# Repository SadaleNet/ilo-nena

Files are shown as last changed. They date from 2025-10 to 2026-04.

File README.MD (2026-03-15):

**(English: Scrolldown for English | toki ike Inli li lon anpa pi toki pona)**

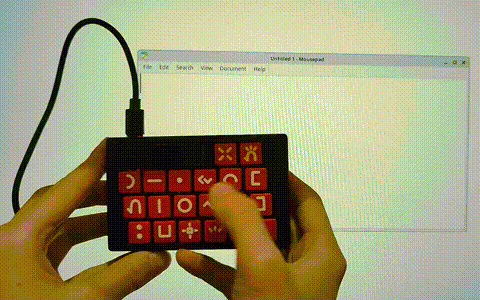
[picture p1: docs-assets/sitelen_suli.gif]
sitelen


* lipu: [https://ilonena.sadale.net/](https://ilonena.sadale.net/)
* sitelen tawa lon ilo Jutu "Youtube": [https://www.youtube.com/watch?v=uy7cPwKw794](https://www.youtube.com/watch?v=uy7cPwKw794)

# ilo nena - ilo pi nasin sitelen Wakalito

ilo nena ni li ken pali e sitelen pona tawa ilo sona kepeken nasin sitelen Wakalito. ilo nena la:

* nasin sitelen Wakalito li lon insa ona
* ken pana e sitelen pona tawa ilo sona kepeken [nasin UCSUR pi sitelen pona](https://www.kreativekorp.com/ucsur/charts/sitelen.html)
* ona li lili. ni li suli ona: 102mm x 64mm x 18mm
* jan li ken pilin e nena ali lon tenpo sama (ni li wile e lipu kiwen sona "PCB rev2")
	* lipu "PCB rev0" en lipu "PCB rev1" la jan li ken pilin e nena tu taso lon tenpo sama. sina ante ala e sona pi ilo nena la nena tu taso li pona. taso sina wile ante e sona ona la ken la sina wile e lipu "PCB rev2". ni la sina esun e lipu "PCB rev0" e lipu "PCB rev1" la o toki tawa mi. mi wile pana e ilo nena sin tawa sina kepeken mani ala.
* jan li ken pana e sona sin tawa ona kepeken nasin "USB"
* sona ali ona li lon. jan ali li ken lukin e ona li ante e ona li pali e ona
* jan li ken pali e ona mute kepeken mani lili kepeken tenpo lili

## nasin kepeken

sina wile kepeken ilo nena la o pali e ni lon ilo sona sina:

1. o kama jo e sitelen "[FairFax HD](https://www.kreativekorp.com/software/fonts/fairfaxhd/)"
2. ilo sona sina li kepeken nasin seme?
	* 🪟 nasin lupa "Windows": o kama jo e ilo [WinCompose](https://github.com/ell1010/wincompose). ilo nena li kepeken nena "R_ALT+U+NANPA".
	* 🐧 nasin soweli "Linux": o pali e ala. ilo nena li kepeken nena "CTRL+SHIFT+U+NANPA"
	* 🍎 nasin kili "Mac OS": o kama jo e nasin "Unicode Hex Input" lon ilo sona sina. ilo nena li kepeken nena "Option+NANPA"
	* nasin ante: ilo nena li ken pana e sitelen Lasin e sitelen UCSUR ala.
3. o kepeken linja "USB". kepeken linja ni la ilo sona sina en ilo nena li kama wan. kin la ilo nena li kama jo e wawa
4. o pilin awen e nena pi nimi ala. sina pilin e ona la o weka ala e palisa luka sina. sina kama lon ma ni la sina ken anu e nasin. o anu e nasin sama nasin pi ilo sona sina:
	* ma anu
	* sina ken anu e nasin kepeken nena "la". sina pini la o pilin e nena "pana"
5. o open e ilo sitelen lon ilo sona sina. o kepeken sitelen "FairFax HD". ni la sina ken pana e sitelen pona kepeken ilo nena a!
6. (ken) tenpo ali la sina kepeken ilo sona pi nasin sama la, sina ken pali e ni:
	* o weka e wawa tan ilo nena sina
	* o pilin awen e nena "weka". ni la o pana e wawa tawa ilo nena. o weka ala e palisa luka sina.
	* o anu e nasin kepeken nena "la" en nena "luka". sina pini la o pilin e nena "pana"
	* wawa li weka la sona pi nasin sina li weka ala

## nasin pi ante sona

nasin nanpa wan: sina ken pana e sona sin tawa ilo nena kepeken ilo "[rv003usb-webflasher](https://github.com/SadaleNet/rv003usb-webflasher)" lon ma ni:

* https://ilonena.sadale.net/sona-sin/

nasin nanpa tu: sina ken pana e sona sin tawa ilo nena kepeken ilo "[minichlink](https://github.com/cnlohr/ch32fun/tree/master/minichlink)" kepeken nasin ni:

1. ilo nena sina o jo ala e wawa.
2. o pilin awen e nena "pana". o weka ala e luka sina.
3. o pana e wawa tawa ilo nena sina kepeken ilo sona sina
4. tenpo ni la ilo nena sina li sitelen e ala lon ma sitelen ona. ni li pona.
5. o kepeken ilo minichlink lon ilo sona sina: `./minichlink -w /ma/pi/sona_sin_sina.bin 0x08000000 -b`

## sona seme li lon?

```
bootloader/      # kepeken sona ni la sina ken pana e sona sin tawa ilo nena kepeken nasin "USB"
cardboard_label/ # sitelen poki
docs-assets/     # sitelen pi lipu README.MD
enclosure/       # selo
keycap_label/    # sitelen lon nena
kicad/           # lipu kiwen sona. ilo nena li jo e lipu kiwen. jan li pana e sona tawa ona la ilo nena li ken pali.
src/             # kepeken sona ni la ilo nena li pali. ilo nena li lukin e nena li pana e sitelen tawa ilo sona.
user_manual/     # jan li lukin e ona la jan ni li kama sona e ilo nena li ken kepeken ona.
full_bom_batch_5.csv  # lipu ni li pana e sona ni: jan li wile pali e ilo nena la ona o esun e ijo seme?
```

## o esun e ilo nena!

sina ken esun e ona lon [esun Sate](https://esun.sadale.net/).

mi jo e mani namako la mi wile pana e ilo nena tawa jan pi mani ala! :)

## o pali e ilo nena!

* o lukin e lipu "README.MD" insa poki ni:
	* `kicad/` -> `keycap_label/` -> `bootloader/` -> `src/` ->  `enclosure/` -> `user_manual/` -> `cardboard_label/`
* o lukin e lipu `full_bom_batch_5.csv`. ni la sina ken esun e ijo pali pi ilo nena.
	* o sona e ni: ilo pali li lon ala lipu ni a! ilo pali li ni: ilo WCH-LinkE en ilo seli en ilo pi pali sitelen en ijo ante.

## jan pona pi ilo nena

jan Sate li pali e ilo nena. taso jan ni li lon ala la ilo nena li ken ala lon:

* jan Sonja li pali e [toki pona](https://en.wikipedia.org/wiki/Toki_Pona)
* jan Likipi en kala pona Tonyu en jan Tepo li pali e [nasin sitelen Wakalito](https://sona.pona.la/wiki/Wakalito)
* jan Osi li pali e [sitelen leko lili](https://toki.pona.billsmugs.com/lipu-tenpo/2022-05-15-sitelen_pona/). sitelen pi ilo nena mi li kepeken ona.
* jan ali pi toki pona. sina kin! :-)

jan ni li pona mute tawa ilo nena. pona tawa sina ali!

## ken

lipu anpa ni li mi ala. sina wile lukin e ken ona la o lukin e nimi insa sitelen insa ona:

* bootloader/bootloader.bin
* src/usb_config.h
* src/generated.c
* src/ilonena.bin - ona li jo e `src/usb_config.h` en `src/generated.c`
* user_manual/lipu_sona.odt en user_manual/lipu_sona.pdf - ona li jo e nimi ali pi nasin sitelen Wakalito

mi pali e lipu ante ali. ken ona li ken "BSD 2-clause".

o sona e ni: mi pali ala e nasin sitelen Wakalito. jan pali pi nasin sitelen Wakalito li toki e ni tawa mi: mi ken pali e ilo nena li pana e ona tawa jan ante. sina pali e ilo nena sama li wile pana e ona tawa jan ante la o toki tawa jan pali pi nasin sitelen Wakalito!

# ilo nena - Toki Pona Unicode Keyboard with Built-in Wakalito Input Method

ilo nena is a purpose-built keyboard for typing sitelen pona glyph of Toki Pona into computers. Feature list:

* Built-in [Wakalito](https://sona.pona.la/wiki/Wakalito) input method
* Supports Unicode output with [sitelen pona UCSUR codepoints](https://www.kreativekorp.com/ucsur/charts/sitelen.html)
* Compact form factor: 102mm x 64mm x 18mm
* NKRO support (since PCB rev2)
	* PCB rev0 and PCB rev1 supported 2KRO only, which's sufficient as long as you don't mod the firmware for non-Wakalito use cases. If you require NKRO and you happened to have ordered/received a unit of older revision, let me know and I'll send you a new one for free.
* Supports USB flashing for firmware update or custom firmware
* Fully open source (firmware, PCBA, enclosure, user manual, etc.)
* Cost-optimized for small volume production. Easy to build your own unit

## Usage

1. Install the font "[FairFax HD](https://www.kreativekorp.com/software/fonts/fairfaxhd/)"
2. Which operating system are you using?
	* 🪟 Windows: Install [WinCompose](https://github.com/ell1010/wincompose). ilo nena uses "R_ALT+U+digits" to type Unicode
	* 🐧 Linux: Supported out of the box for most linux distros. ilo nena uses "CTRL+SHIFT+U+digits"
	* 🍎 Mac OS: Configure and use the built-in "Unicode Hex Input". ilo nena uses "Option+digits"
	* Others: ilo nena has Latin (ASCII) mode that's compatible with all devices. However, it couldn't output Unicode in this mode. You would need a font that supports conversion between Latin to sitelen pona such as FairFax Pona HD.
3. Connect USB cable, one side with ilo nena, another side with your computer
4. Hold the space key to enter the config screen below:
	* Configuration screen
	* press the "la" key (leftmost column, topmost row) to select the OS. Once done, press the "pana" key (the yellow key on the rightmost column)
5. Launch any text editing software and select the font "FairFax HD". You're all set! Now that you can type sitelen pona with ilo nena!
6. (Optional) Here's how you set the default OS to use upon powering on the ilo nena:
	* Remove power from ilo nena
	* Hold the "weka" key (the yellow key on second column to the right) and connect USB cable.
	* Select configuration with the "la" key and the "luka" key (leftmost column, central row). After you're done, press the "pana" key
	* Your default settings is saved to ilo nena and preserved across power cycles

## Firmware Update

Method 1: Firmware update can be done with "[rv003usb-webflasher](https://github.com/SadaleNet/rv003usb-webflasher)":

* Web-based update tool with instruction (in Toki Pona only): https://ilonena.sadale.net/sona-sin/

Method 2: Firmware update can be performed via USB with "[minichlink](https://github.com/cnlohr/ch32fun/tree/master/minichlink)". Instruction:

1. Remove power from ilo nena
2. Hold the "pana" key (the yellow key on the rightmost column)
3. Connect USB cable, one side to your computer, another side to ilo nena
4. While in firmware update mode, the display of ilo nena would show nothing, which is intended
5. Run this command on your computer: `./minichlink -w /path/to/firmware.bin 0x08000000 -b`

## Repo Structure

```
bootloader/      # Bootloader for providing USB firmware update functionality (a patch against rv003usb)
cardboard_label/ # Label slapped onto the packaging cardboard
docs-assets/     # Images for README.MD
enclosure/       # The 3D printed enclosure design
keycap_label/    # The keycap label design printed onto UV DTF transfer sheet
kicad/           # Electronics design
src/             # Firmware source code
user_manual/     # User manual source and PDF
full_bom_batch_5.csv  # Full BOM with price assuming batch of 5 units
```

## Ordering (Not recommended)

As I'm operating on a non-profit basis with my own free labor, to avoid burn out and limit the scale of operation, this device is only available for order to Toki Pona speakers.

I do not recommend that but if you really want it that badly and you don't speak Toki Pona, please use a contact method mentioned in [sadale.net](https://sadale.net/). Tell me your situation. I might be able to arrange something for you.

## Build your Own Unit (Recommended)

* Just follow the the README files inside the folders in the following sequence:
	* `kicad/` -> `keycap_label/` -> `bootloader/` -> `src/` ->  `enclosure/` -> `user_manual/` -> `cardboard_label/`
* A full BOM `full_bom_batch_5.csv` is available for your procurement reference
	* Warning: The BOM doesn't contain equipments like WCH-LinkE programmer, soldering iron, printer, etc.

## Credits

ilo nena was developed by Sadale (jan Sate). This project wouldn't have been possible without the following prior works:

* jan Sonja: Created [Toki Pona langauge](https://en.wikipedia.org/wiki/Toki_Pona)
* jan Likipi, kala pona Tonyu and jan Tepo: Developed [Wakalito](https://sona.pona.la/wiki/Wakalito) input method for sitelen pona
* jan Osi: Created the public domain font [sitelen leko lili](https://toki.pona.billsmugs.com/lipu-tenpo/2022-05-15-sitelen_pona/), which's embedded into ilo nena
* All of the Toki Pona speakers around the world! This product's useless without a solid community! :-)

For all of the people above, you have my gratitude. Thank you very much!

## License

The following files are adapted from external sources. Please read the comment inside the files to view the license information:

* bootloader/bootloader.bin - Built from MIT license source
* src/usb_config.h - Adapted from MIT license source
* src/generated.c - Contains font and strings generated from external files
* src/ilonena.bin - Built with `src/usb_config.h` and `src/generated.c`
* user_manual/lipu_sona.odt and user_manual/lipu_sona.pdf - Contains lookup table of Wakalito input method

All other files are my own and they're licensed under BSD 2-clause license.

Reminder: I do not own the design of Wakalito input method included in the `src/generated.c` file. I've obtain the permission from the Wakalito authors for making it "as long as it isn't made with profit in mind". If you want to make your own unit and redistribute/sell that, please ask the authors of Wakalito for permission.

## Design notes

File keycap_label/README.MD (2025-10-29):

**(English: Scrolldown for English | toki ike Inli li lon anpa pi toki pona)**

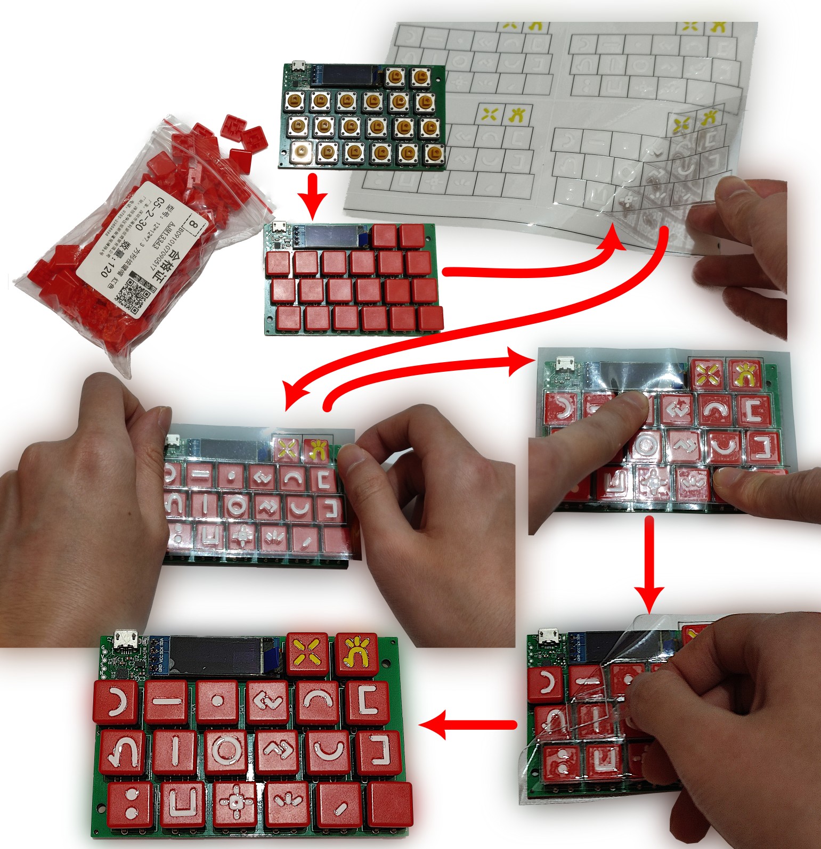
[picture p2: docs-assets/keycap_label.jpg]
nasin pi pana sitelen tawa nena


# sitelen nena

kepeken nasin ni la sina ken pana e sitelen tawa nena pi ilo nena:

1. o pali e lipu `ilonena-label.png` kepeken nasin "UV DTF". suli sitelen li ni: 89.2x56.2mm
2. o pana e selo nena tawa nena ali. suli ona li ni: 12x12mm
3. o kama jo e lipu `ilonena-label.png` li pana e ona lon sewi nena pi ilo nena
4. o pilin e nena ali. sitelen li kama lon nena
5. sitelen ali pi lipu `ilonena-label.png` li kama lon nena. lipu ni li kama lipu pi sitelen ala. o weka e lipu pi sitelen ala

# Keycap labels

Here's how you could apply labels on the buttons of ilo nena:

1. Send `ilonena-label.png` to a UV DTF printing shop. The dimensions of the graphic is 89.2x56.2mm
2. Install key caps. The dimensions of the keycap is 12x12mm.
3. Peel off the UV DTF sticker sheet and carefully align it with the buttons using the printed frame. Then put the entire sticker on the buttons of ilo nena.
4. Apply pressure to the buttons by pressing each of them a few times, making the symbols sticking with the buttons.
5. Peel off the sticker from the buttons, leaving the symbols on the buttons.

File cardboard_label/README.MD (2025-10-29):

**(English: Scrolldown for English | toki ike Inli li lon anpa pi toki pona)**

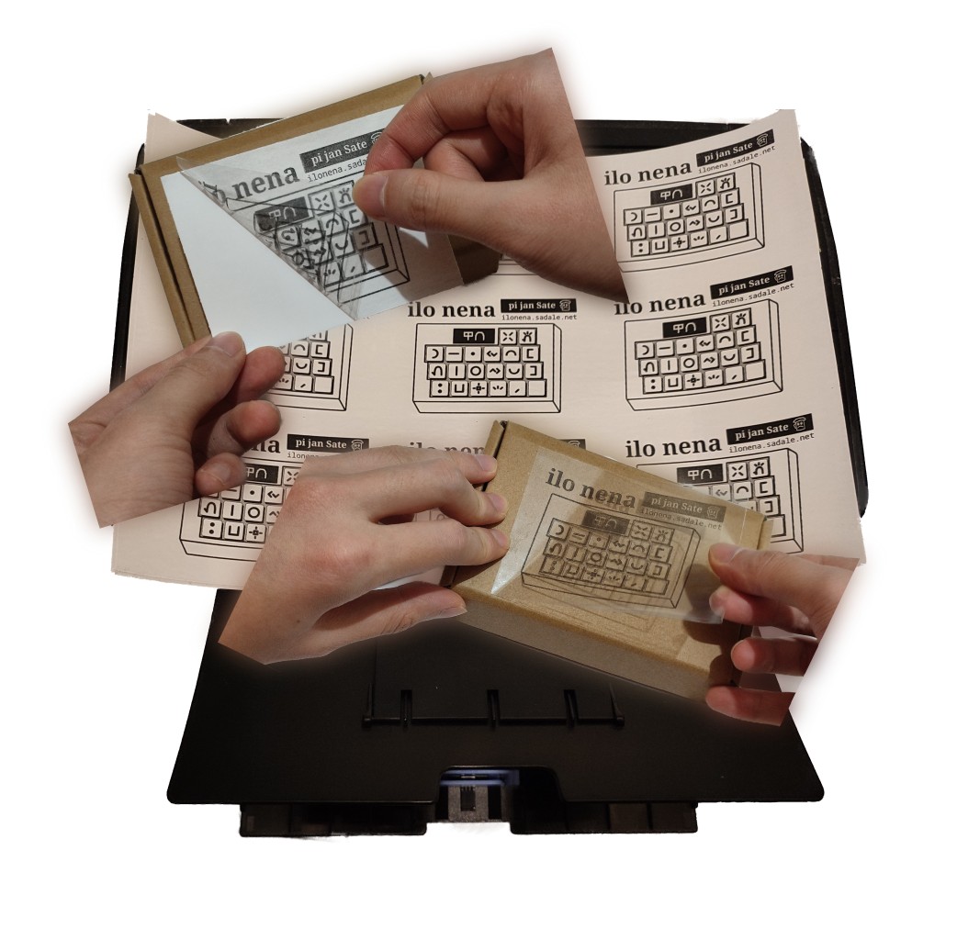
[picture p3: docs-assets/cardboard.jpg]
nasin pi pana sitelen tawa poki pi ilo nena


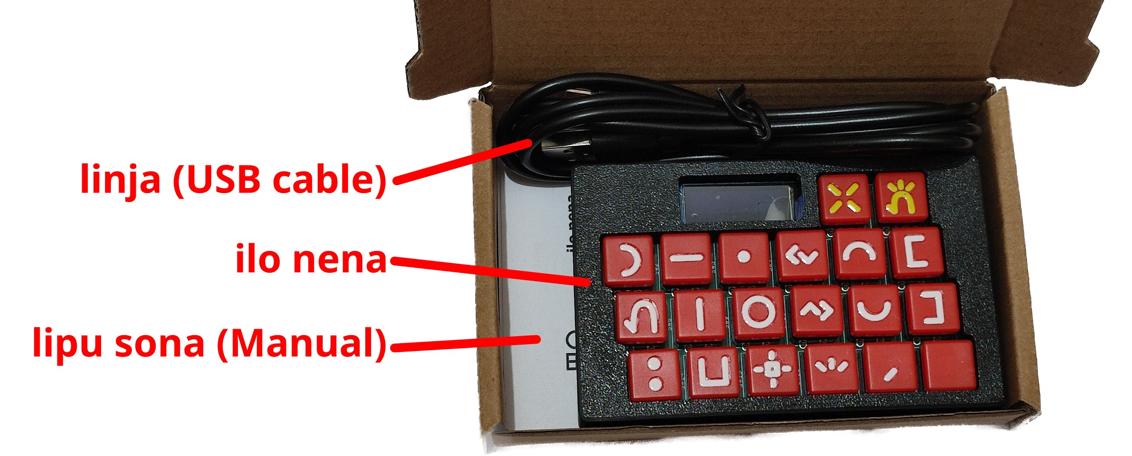
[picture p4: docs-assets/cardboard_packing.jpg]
ali insa poki


# sitelen poki

sitelen ni li lon poki pi ilo nena. nasin kepeken:

1. o kama jo e lipu pi suli "A4".
2. o pana e sitelen `cardboard_label.jpg` tawa lipu (lipu `cardboard_label.jpg` li tan lipu `cardboard_label.svg`)
3. lipu suli wan o kama lipu lili mute
4. o pana e lipu lili wan tawa poki wan. o pana e lipu lili nanpa tu tawa poki nanpa tu. ni la o kepeken lipu lili ali sina.

## o poki e ali!

poki li jo e ilo nena e lipu sona e linja USB MicroB (suli ona li 1.5m):

suli poki li ni: 130x80x25mm

# Cardboard Label

To print:

1. Get an A4-sized sticker that you can print on.
2. Print `cardboard_label.jpg` (Its source file is `cardboard_label.svg`)
3. Cut it into 9 pieces with a paper cutter
4. Put each of the stickers onto the surface of the cardboard

## Packing

Pack the items as shown on the photo way above. The package contains ilo nena unit, user manual and 1.5m USB microB cable. The cardboard's dimensions is "130x80x25mm".

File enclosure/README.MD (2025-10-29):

**(English: Scrolldown for English | toki ike Inli li lon anpa pi toki pona)**

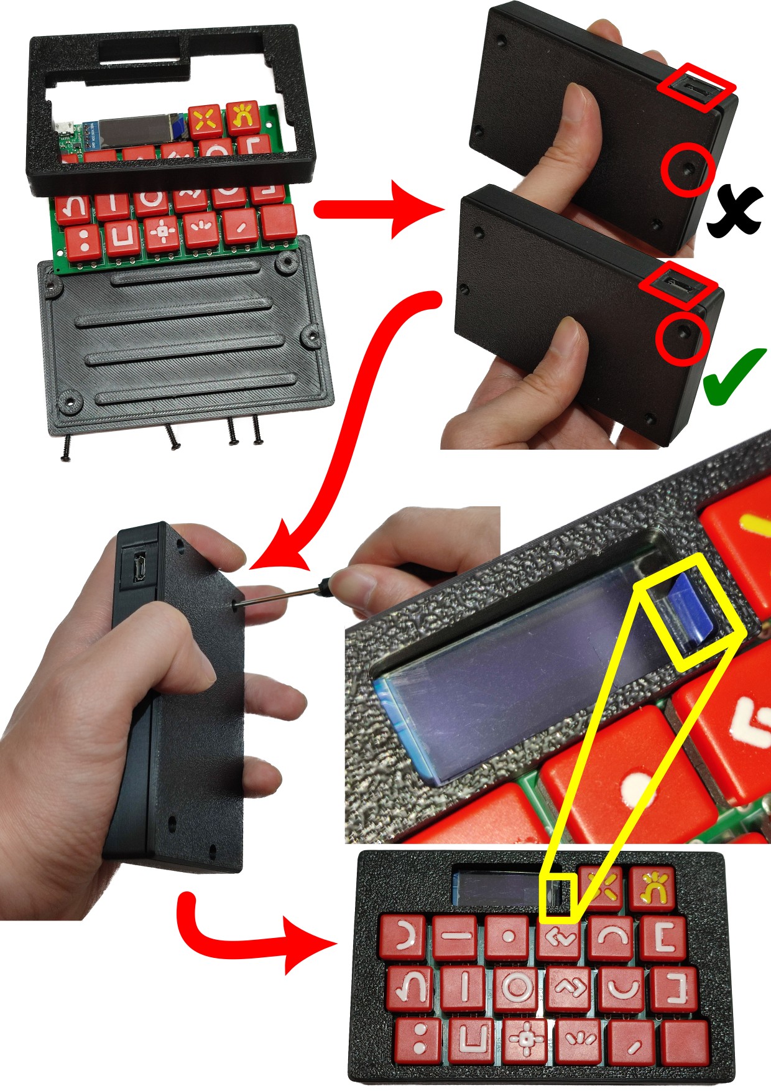
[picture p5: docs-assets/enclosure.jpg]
nasin wan pi selo


# selo

sina ken pali e selo kepeken ilo pi pali selo "3D printer". mi kepeken kiwen pimeja "ABS".

selo li jo e ijo tu. ijo `ilonena_enclosure-Bottom.stl` en ijo `ilonena_enclosure-Top_Rotated.stl`. sina ken pali e selo kepeken nasin ni:

1. o kama jo e palisa "PA2.3x10" tu tu.
2. o sike ala e ijo `ilonena_enclosure-Bottom.stl`
3. o pana e lipu sona insa selo. o wan e ali kepeken palisa "PA2.3x10". kin la o sewi lili e lipu pi ilo sitelen.

sina ken ante e selo ni kepeken lipu `ilonena_enclosure.FCStd`.

# Enclosure

The STL files can be manufactured by using 3D printer.

The material I used is black ABS. I outsourced to a 3D printing service provider.

Here's the assembly procedure:

1. Obtain four PA2.3x10 self-tapping screws
2. Mind the orientation of the `ilonena_enclosure-Bottom.stl`
3. Sandwich the PCBA between the two enclosure parts and install the four screws with a screw driver. Make sure to position the tip of the screen protection film of the OLED such that it can be peeled off.

See the pic way above for the assembly procedure. `ilonena_enclosure.FCStd` is the source file that you can modify.

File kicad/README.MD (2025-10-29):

**(English: Scrolldown for English | toki ike Inli li lon anpa pi toki pona)**

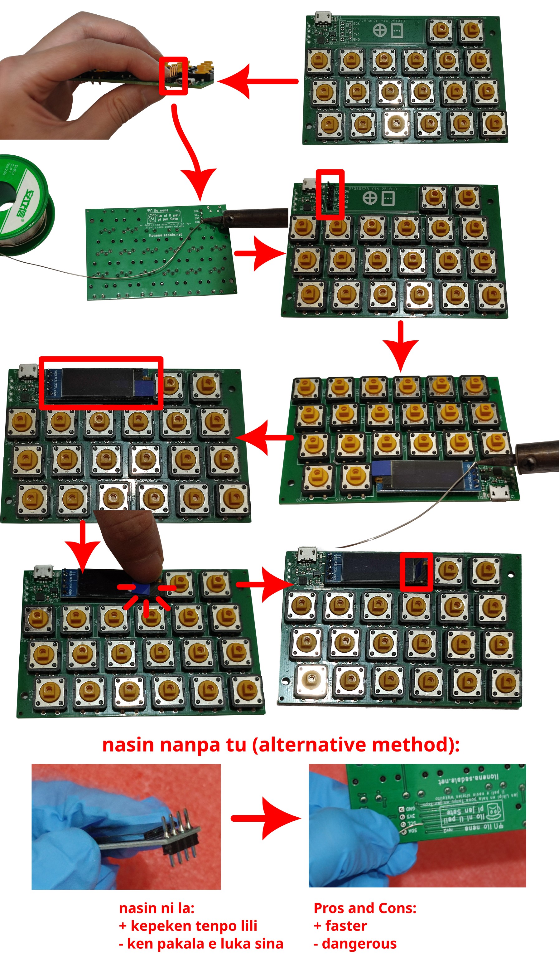
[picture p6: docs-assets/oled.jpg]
nasin pana pi ilo sitelen


# lipu kiwen sona

ma ni li jo e sona pi lipu kiwen. mi pali e ona kepeken ilo "KiCad" en ilo lili "[Fabrication-Toolkit](https://github.com/bennymeg/Fabrication-Toolkit)".

sina ken esun e lipu kiwen sona kepeken nasin ni:

1. o open e lipu `production.zip`
2. insa lipu `production.zip` la o pana e ni tawa tomo pali: lipu `ilonena.zip` li lipu "gerber". lipu `bom.csv` en lipu `positions.csv` li lipu "SMT". mi kepeken tomo pali "JLCPCB".
3. o pana e mani tawa tomo pali. ni la sina o awen. lipu kiwen sona li jo e ijo mute. taso ilo sitelen li lon ala.

o pana e ilo sitelen tawa lipu kiwen sona kepeken nasin ni:

1. o esun e ilo sitelen e palisa kulupu. nimi pi ilo sitelen li ni: SSD1306 128x32 0.91" OLED I2C
2. o pana e palisa kulupu tawa lipu kiwen sona
3. o pana e ilo sitelen lon sewi pi palisa kulupu.
4. o pana e wawa tawa lipu lili pi ilo sitelen

# PCBA Source and Production Files

This folder contains the source and production files for the PCBA of ilo nena. It uses KiCad with production files generated with the plugin "[Fabrication-Toolkit](https://github.com/bennymeg/Fabrication-Toolkit)".

To order PCBA on your own:

1. Extract `production.zip`
2. Inside the extracted files, send `ilonena.zip` as gerber. `bom.csv` and `positions.csv` as SMT files. I used JLCPCB for the PCBA.
3. Pay up and wait for delivery. The PCBA has all electronic parts except for the OLED screen, which you need to solder that on your own.

Soldering the OLED:

1. Purchase SSD1306 128x32 0.91" OLED I2C and its 2.54mm 4p pin header
2. Solder the pin header onto the board with a soldering iron.
3. Solder the OLED on top of the pin header.
4. Fold the peeling tab of the OLED so that it would be exposed and accessible thru the enclosure

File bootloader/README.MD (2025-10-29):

**(English: Scrolldown for English | toki ike Inli li lon anpa pi toki pona)**

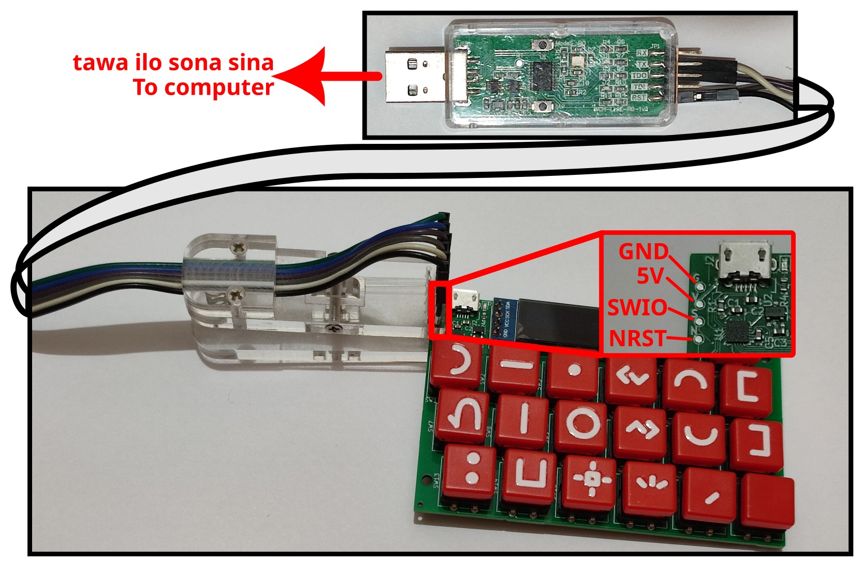
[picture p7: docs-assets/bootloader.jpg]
nasin pi pana ilo "Bootloader"


# ilo "Bootloader" li seme?

* kepeken ilo ni la jan li ken pilin e nena "pana" li pana e sona sin tawa ilo nena kepeken nasin "USB".
* lipu `bootloader.patch` li ante e lipu ni kepeken ilo `git apply`: https://github.com/cnlohr/rv003usb/tree/35e0f688a9a041ed8cec37fcbb458df095dc0d79 ni la sina ken pali e lipu `bootloader.bin`
* tenpo pini la mi kin li pali e lipu `bootloader.bin`. sina ken kepeken e ona e lipu `bootloader.patch` ala.
* sina ken pana e ilo ni tawa ilo nena kepeken ilo tu ni lon tenpo sama: ilo "WCH-LinkE" en ilo "minichlink". o kepeken nimi ni: `./minichlink -a -w bootloader.bin bootloader -B`
* kin la sina o kepeken nimi ni: `./minichlink -w +a55af708 option`. sina kepeken ala nimi ni la ilo ni li pali ala a!

## ken

jan Sate li pali ala e ilo ni. jan "CNLohr" li pali e ona. ken ona li ken "MIT License".

# Bootloader of ilo nena

* Provides USB flashing functionality by holding the "pana" key upon boot
* Requires WCH-LinkE to flash the bootloader itself
* `bootloader.patch` is to be applied with `git apply` against the following repo's commit: https://github.com/cnlohr/rv003usb/tree/35e0f688a9a041ed8cec37fcbb458df095dc0d79 . You can build `bootloader.bin` with it on your own. The patch enables the hold-button-to-enter-bootloader functionality.
* You can also use the `bootloader.bin` pre-built binary in this folder instead of building the bootloader on your own
* To flash, WCH-LinkE and minichlink are required. Run the following command after connecting ilo nena with WCH-LinkE: `./minichlink -a -w bootloader.bin bootloader -B`
* Contrary to the specs of CH32V003, I empirically found that it came with bootloader disabled (USER=0x17 instead of 0xF7). Please enable the bootloader with the following command: `./minichlink -w +a55af708 option`

## License

I'm not the author of the bootloader. It's created by CNLohr released under MIT License.

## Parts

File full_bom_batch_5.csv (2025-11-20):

tomo esun | ijo | mani seme? | mani kulupu | suli kulupu | nanpa wile | mani USD pi ilo nena wan | pakala | mani USD pi pakala ala | mani pi poki tawa | mani USD pi poki tawa | linja esun
Supplier | Item | Cost Unit | Cost at MOQ | MOQ | Quantity | USD per unit | Scrap Rate | USD per unit post-scrap | Shipping fee | USD shipping fee | URL
JLCPCB | PCBA | USD | 43 | 5 | 1 | 8.60 | 0.10 | 9.56 | 5 | 6.00 | https://jlcpcb.com/
启望3D | Enclosure ABS Black/FDM | RMB | 7 | 1 | 1 | 1.08 | 0.05 | 1.13 | 8 | 1.23 | https://item.taobao.com/item.htm?id=844902360181
信诚新电子 | OLED 0.91" SSD1306 128x32 white, non-soldered | RMB | 6 | 1 | 1 | 0.92 | 0.05 | 0.97 | 2 | 0.31 | https://item.taobao.com/item.htm?id=799718292351&skuId=5926153899425
小福水晶标厂 | Keycap Label (UV DTF Sheet) | RMB | 20 | 10 | 1 | 0.31 | 0.20 | 0.38 | 0 | 0.00 | https://item.taobao.com/item.htm?id=694929996955&skuId=5221531111683
telesky旗舰店 | Keycap, Red 12x12 | RMB | 2 | 30 | 20 | 0.21 | 0.20 | 0.26 | 0 | 0.00 | https://detail.tmall.com/item.htm?id=548295391131&skuId=3325455760644
固万基五金科技 | PA2.3x10 self-tapping screw | RMB | 2.23 | 100 | 4 | 0.01 | 0.05 | 0.01 | 0 | 0.00 | https://item.taobao.com/item.htm?id=39879981066&skuId=5040813371982
专正电子厂 | USB MicroB Cable Black 1.5m (37+37+13+13 stranded) | RMB | 0.76 | 1 | 1 | 0.12 | 0.05 | 0.12 | 4 | 0.62 | https://item.taobao.com/item.htm?id=575077271834&skuId=4873575713304
chuanyue旗舰店 | Cardboard Box 130x80x25 (hardness level 4) | RMB | 6.65 | 50 | 1 | 0.02 | 0.20 | 0.03 | 0 | 0.00 | https://detail.tmall.com/item.htm?id=710482007210&skuId=4977614272113
- | Recycled Bubble Wrap | RMB | 0 | 1 | 1 | 0.00 | 0.00 | 0.00 | 0 | 0.00 | -
图业包装 | Shipping bag 15x25cm | RMB | 5.5 | 100 | 1 | 0.01 | 0.10 | 0.01 | 0 | 0.00 | https://item.taobao.com/item.htm?id=614164738722&skuId=4929636989133
启盛不干胶 | A4 transparent label on cardboard | RMB | 8.41 | 10 | 0.11 | 0.01 | 0.20 | 0.02 | 1 | 0.15 | https://item.taobao.com/item.htm?id=829873444197&skuId=5732144007104
神州集运 | Shipping fee from mainland China warehouse to HKSAR | RMB | 0 | 1 | 0.11 | 0.00 | 0.00 | 0.00 | 23 | 3.54 | -
安立信旗舰店 | Lead-free soldering coil | RMB | 24.8 | 1 | 0.01 | 0.04 | 0.00 | 0.04 | 0 | 0.00 | https://detail.tmall.com/item.htm?id=588626885887&skuId=5970012670897
(Any store IRL) | Toner cartridge for printing on label P2500 | HKD | 350 | 1 | 0.000063 | 0.00 | 0.00 | 0.00 | 0 | 0.00 | -
- | Electricity for soldering (says 0.1kWh) | HKD | 0.1 | 1 | 1 | 0.01 | 0.00 | 0.01 | 0 | 0.00 | -
- | mani ali (Total Cost) | USD | - | - | - | - | - | 12.55 | - | 11.85 | -
 |  |  |  |  |  |  |  | ^ mani pi ilo nena wan ^ |  | ^ mani pi poki tawa ^
 |  |  |  |  |  |  |  | ^ Total cost per unit ^ |  | ^ Shipping fee per batch ^

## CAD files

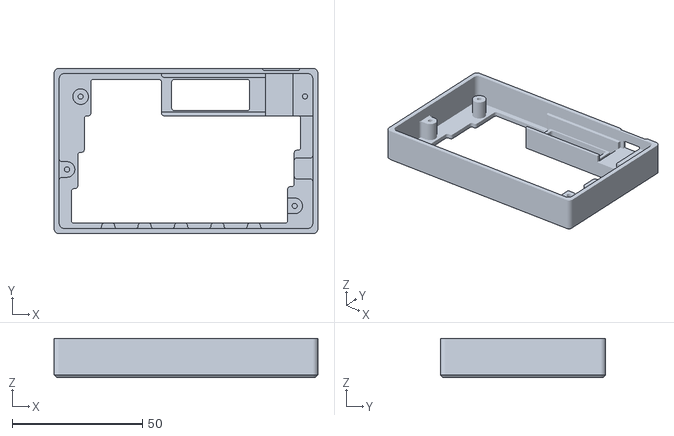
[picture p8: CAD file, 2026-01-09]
enclosure/ilonena_enclosure-Top_Rotated.stl
101.5 x 63.6 x 15.0

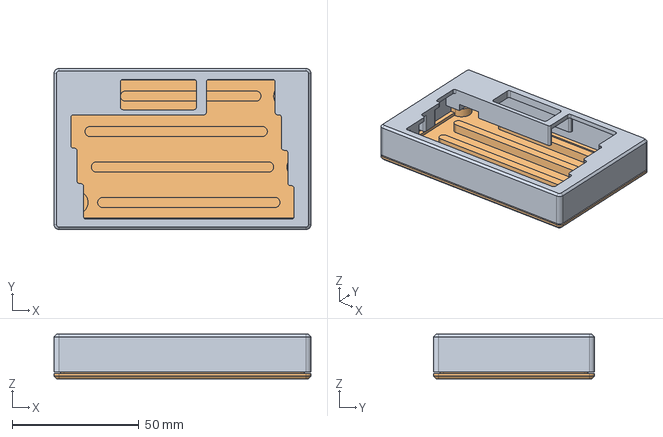
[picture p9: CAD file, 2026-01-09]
enclosure/ilonena_enclosure.FCStd
101.5 x 63.6 x 17.6 mm
Top
Bottom

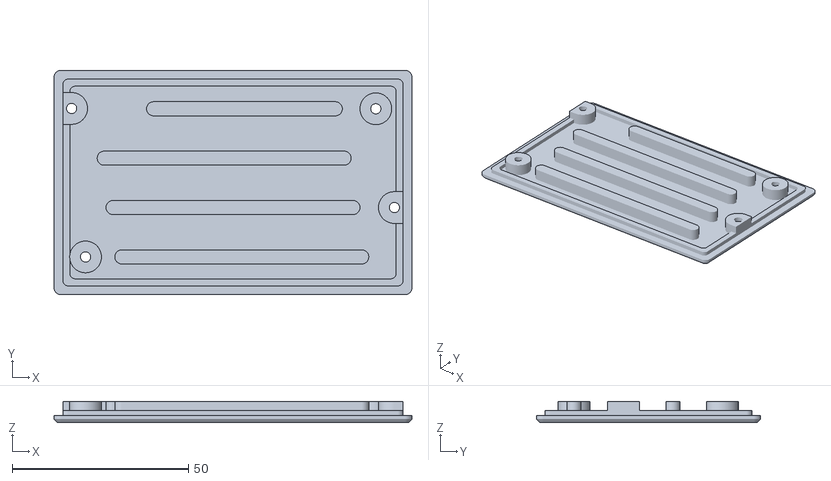
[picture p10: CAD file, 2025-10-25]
enclosure/ilonena_enclosure-Bottom.stl
101.5 x 63.6 x 6.00

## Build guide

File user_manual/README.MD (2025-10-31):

**(English: Scrolldown for English | toki ike Inli li lon anpa pi toki pona)**

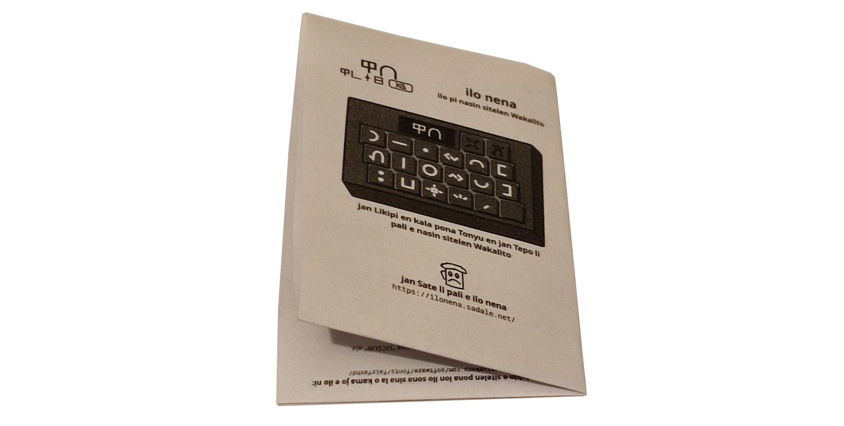
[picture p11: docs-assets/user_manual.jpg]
lipu sona pi ilo nena


# lipu sona

sina ken pali e lipu sona kepeken nasin ni:

1. o kama jo e lipu pi suli "A5". sina tu e lipu "A4" wan la ona li kama lipu "A5" tu.
2. o pana e `lipu_sona.pdf` tawa lipu "A5" sina.
3. o lili e lipu kepeken luka sina. lipu sona li kama lon:

lipu sona li lukin ike la o ante e lipu `lipu_sona.pdf` kepeken nasin ni:

1. o open e lipu `lipu_sona.odt` kepeken ilo "LibreOffice"
2. o pilin e nena "File > Print"
3. o ante e nanpa lon ma ni:

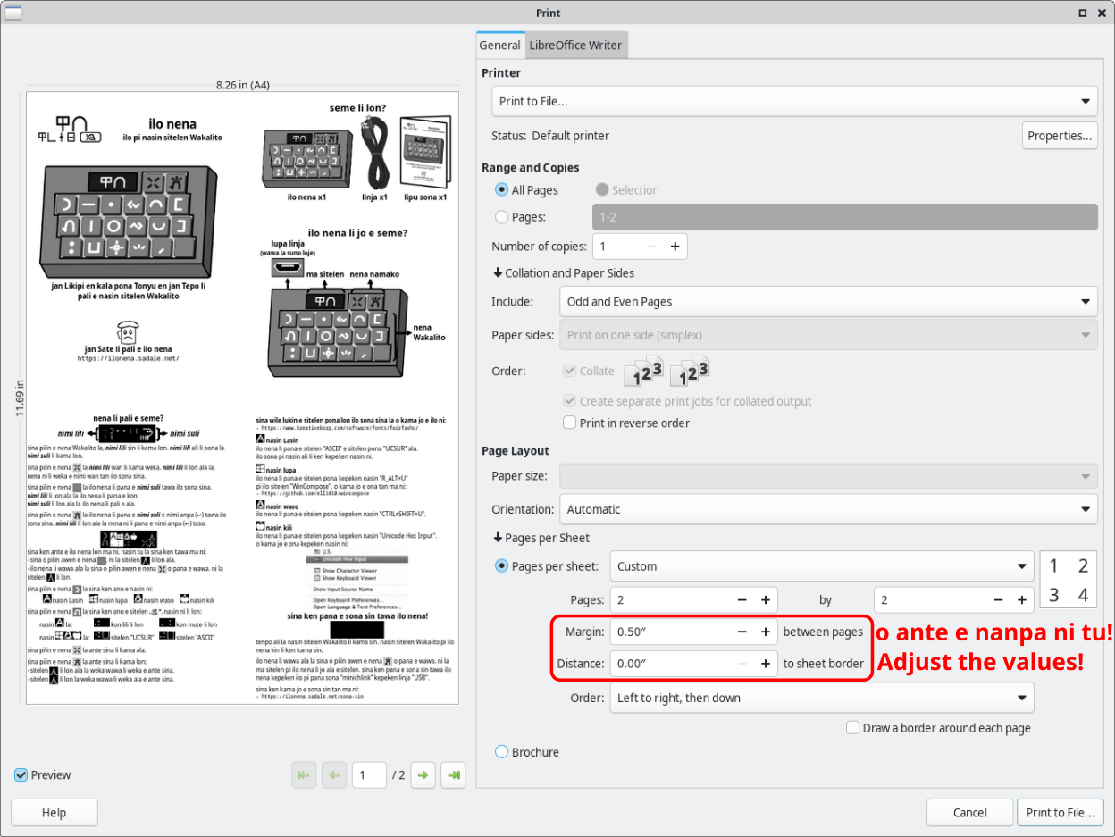
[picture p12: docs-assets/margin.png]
sitelen ni li pana e sona ni: jan o ante e nanpa seme?


4. o pilin e nena "Print to file". ni la lipu "PDF" sin li kama.
5. o kepeken lipu "PDF" sin. ona li lukin ike o awen ante e nanpa kepeken nasin sama.

# Paperback User Manual

To print:

1. Get an A5-sized paper. It can be obtained by cutting A4-sized paper into two-halves.
2. Print `lipu_sona.pdf` with margin added to the edge.
3. Fold the user manual twice as shown on the photo way above (in the toki pona version of the instruction)

The required margin varies between different printers and OS configurations. Here's how to adjust the margin in case the user manual looked wrong:

1. Open `lipu_sona.odt` with LibreOffice
2. Click on File > Print
3. Adjust the margin as shown in the screenshot way above (in the toki pona version of the instruction)
4. Click on "Print to file" to generate a PDF file with correct margin.
5. Print out the PDF file and see if the margin is correct. If not, adjust the margin again until you got it right.

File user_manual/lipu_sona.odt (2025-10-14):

ilo nena ilo pi nasin sitelen [Wakalito] | ilo nena ilo pi nasin sitelen Wakalito

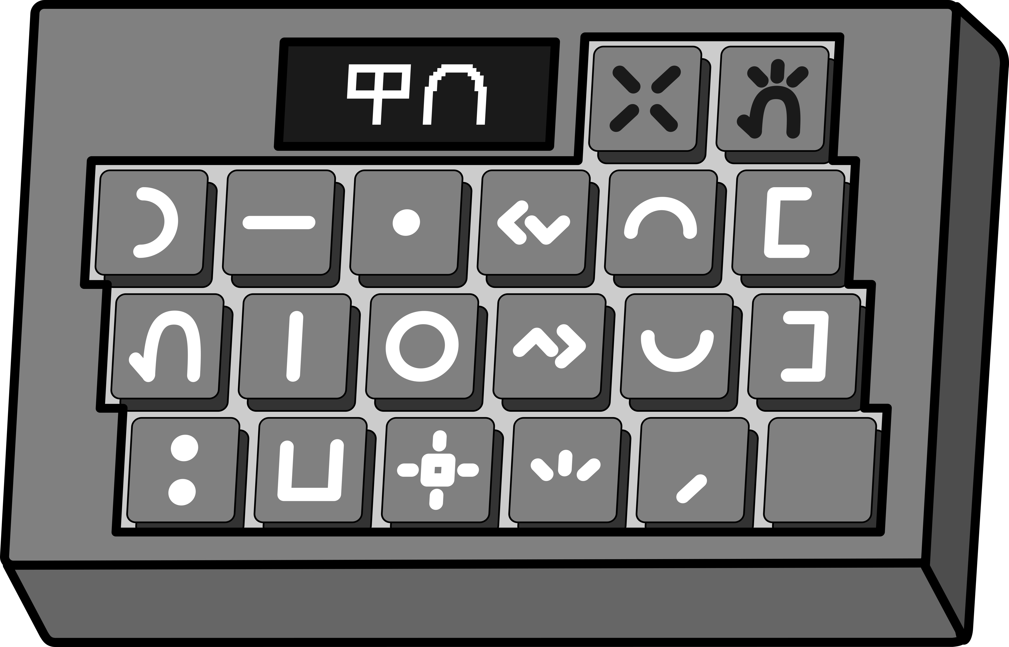
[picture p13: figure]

jan Likipi en kala pona Tonyu en jan Tepo li

pali e nasin sitelen Wakalito

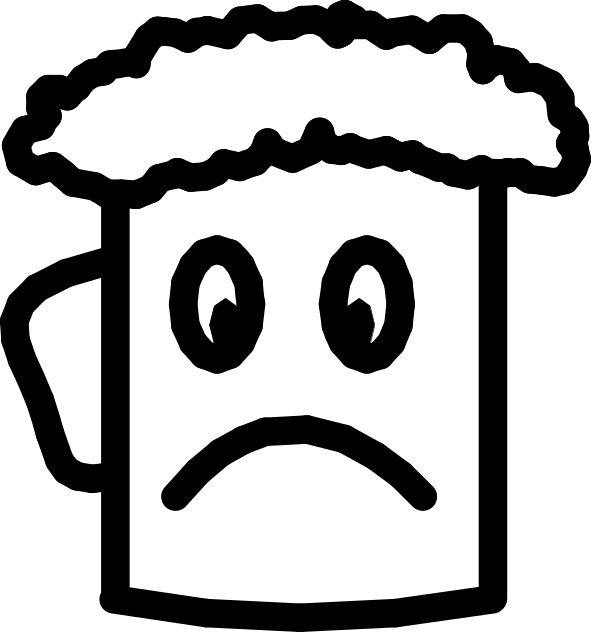
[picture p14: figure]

jan Sate li pali e ilo nena

https://ilonena.sadale.net/

seme li lon?

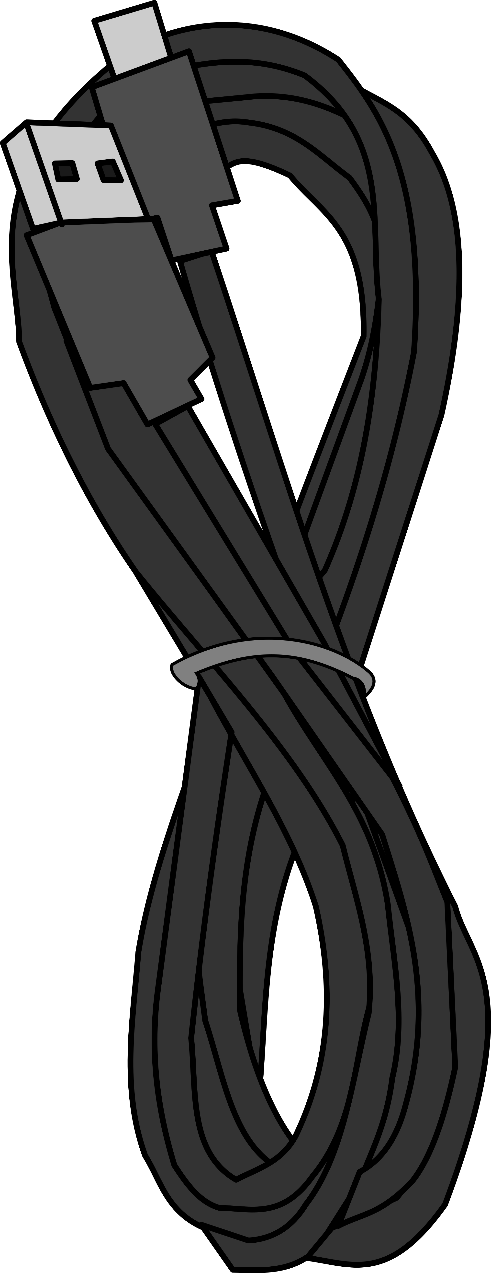
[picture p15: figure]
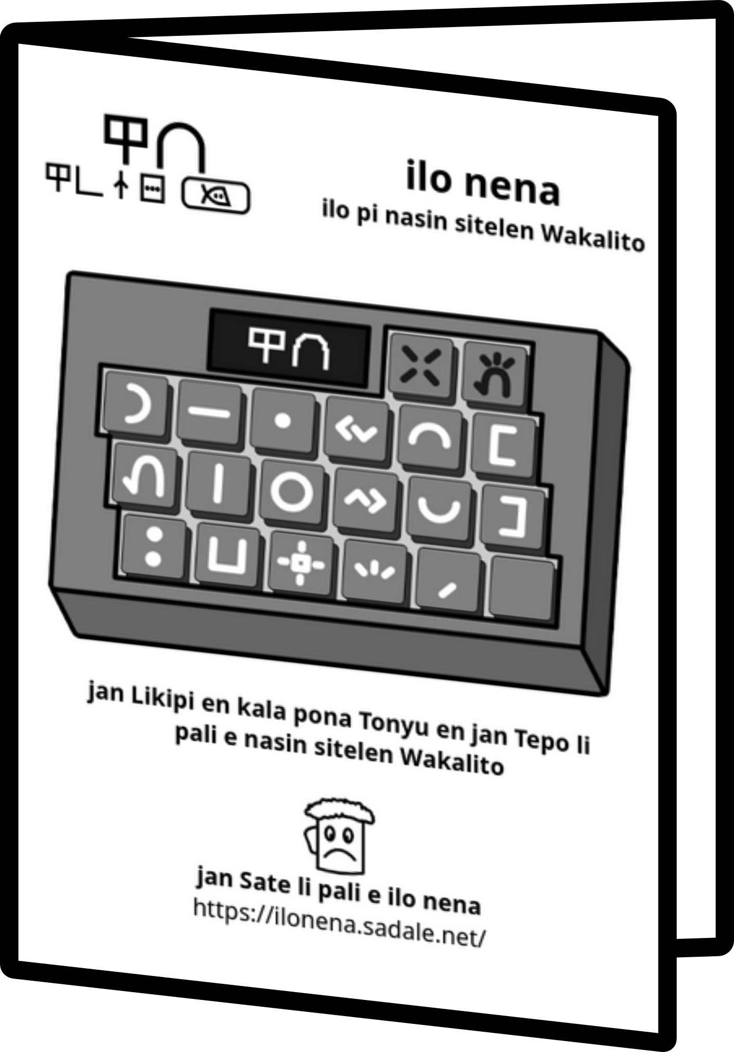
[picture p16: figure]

ilo nena x1 | linja x1 | lipu sona x1

ilo nena li jo e seme?

lupa linja

(wawa la suno loje)

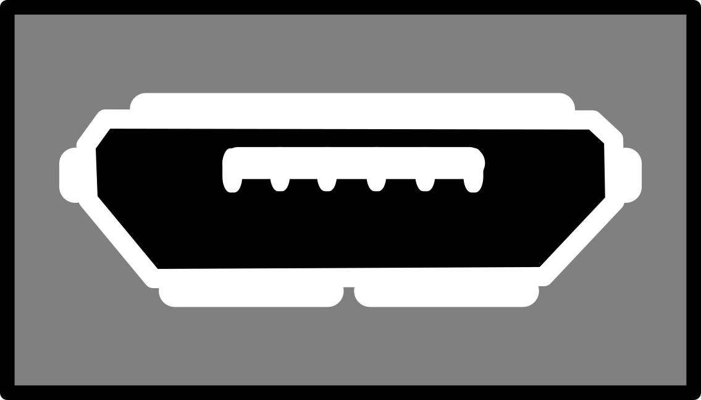
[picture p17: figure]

ma sitelen nena namako

nena Wakalito

nena li pali e seme?

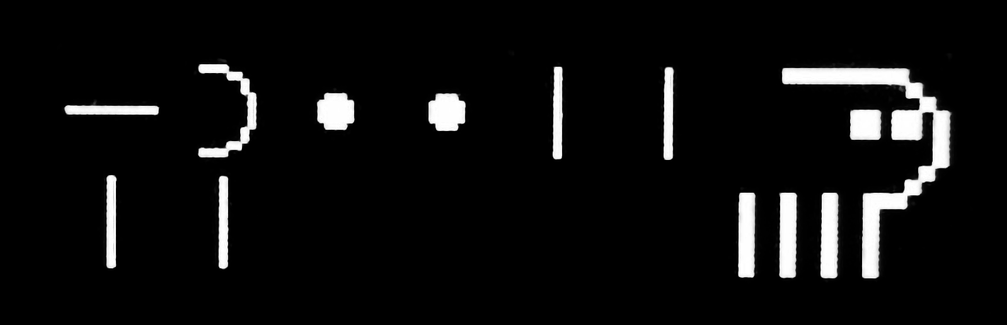
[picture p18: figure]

nimi lili | | nimi suli

sina pilin e nena Wakalito la, nimi lili sin li kama lon. nimi lili ali li pona la nimi suli li kama lon.

sina pilin e nena la nimi lili wan li kama weka. nimi lili li lon ala la, nena ni li weka e nimi wan tan ilo sona sina.

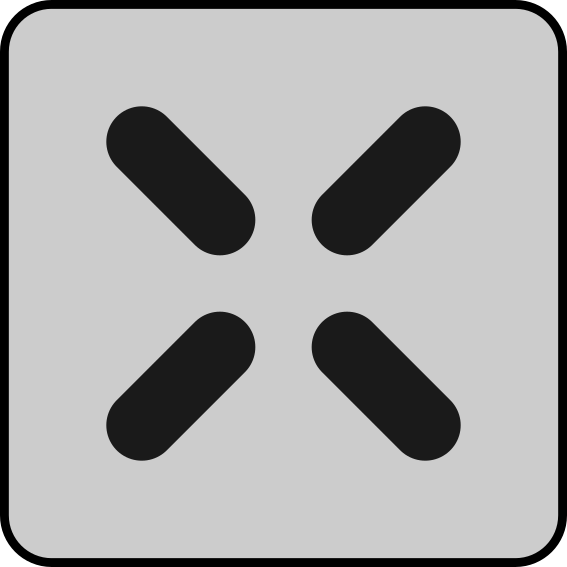
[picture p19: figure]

sina pilin e nena la ilo nena li pana e nimi suli tawa ilo sona sina.

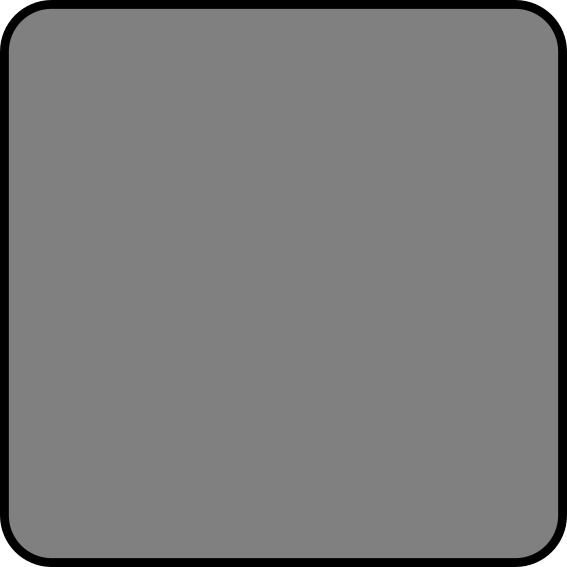
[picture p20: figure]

nimi lili li lon ala la ilo nena li pana e kon.

nimi suli li lon ala la ilo nena li pali e ala.

sina pilin e nena la ilo nena li pana e nimi suli e nimi anpa (↵) tawa ilo sona sina. nimi lili li lon ala la nena ni li pana e nimi anpa (↵) taso.

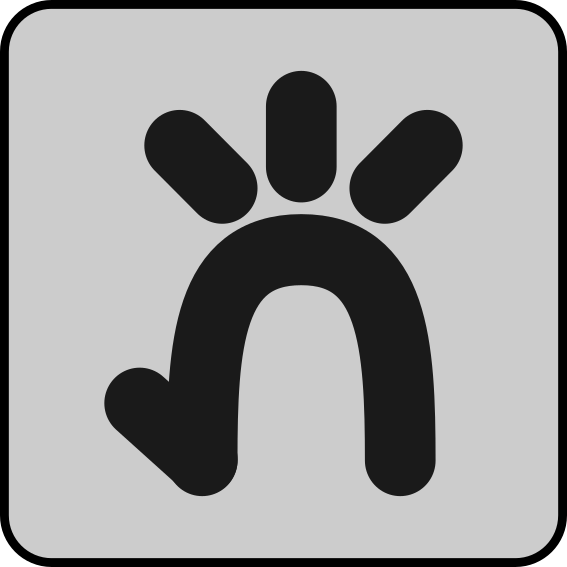
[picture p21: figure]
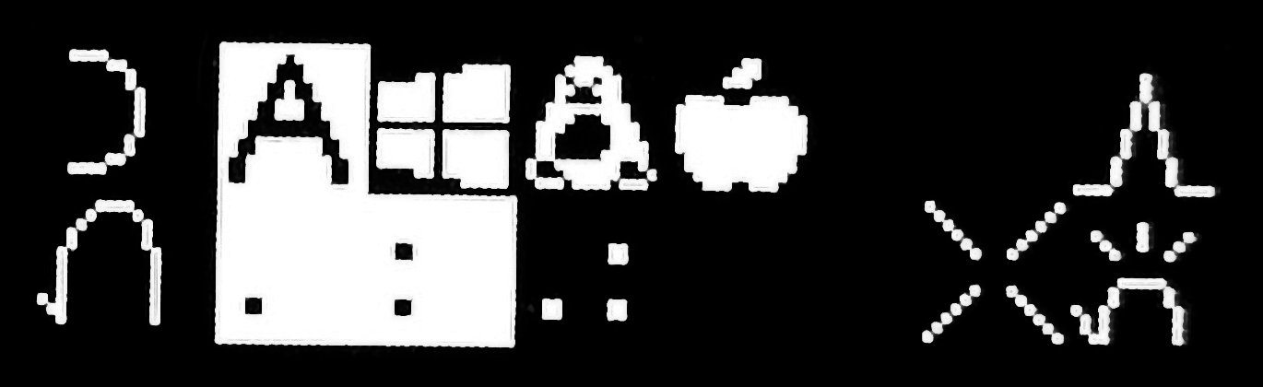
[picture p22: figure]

sina ken ante e ilo nena lon ma ni. nasin tu la sina ken tawa ma ni:

- sina o pilin awen e nena . ni la sitelen li lon ala.

- ilo nena li wawa ala la sina o pilin awen e nena o pana e wawa. ni la sitelen li lon.

sina pilin e nena la sina ken anu e nasin ni:

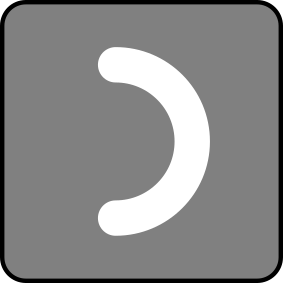
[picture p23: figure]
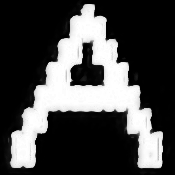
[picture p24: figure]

nasin Lasin nasin lupa nasin waso nasin kili

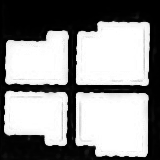
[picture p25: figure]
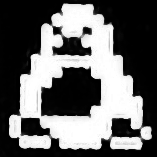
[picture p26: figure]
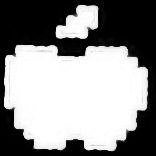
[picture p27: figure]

sina pilin e nena la sina ken anu e sitelen .:[],". nasin ni li lon:

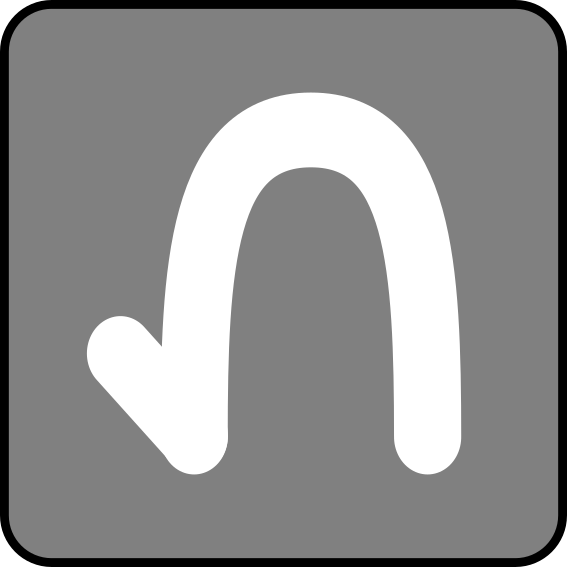
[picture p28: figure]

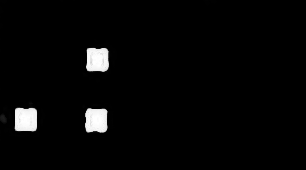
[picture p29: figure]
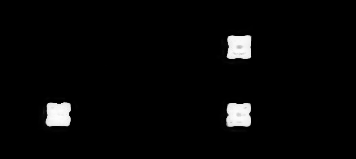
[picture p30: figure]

nasin la: | kon lili li lon | kon mute li lon

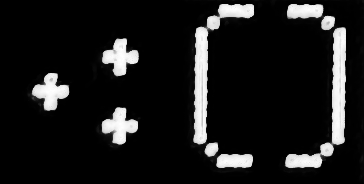
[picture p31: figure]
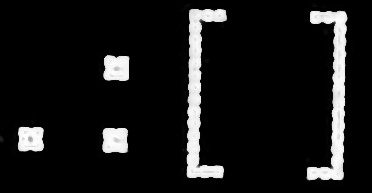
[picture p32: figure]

nasin la: | sitelen "UCSUR" | sitelen "ASCII"

sina pilin e nena la ante sina li kama ala.

sina pilin e nena la ante sina li kama lon:

- sitelen li lon ala la weka wawa li weka e ante sina.

- sitelen li lon la weka wawa li weka ala e ante sina.

sina wile lukin e sitelen pona lon ilo sona sina la o kama jo e ilo ni:

- https://www.kreativekorp.com/software/fonts/fairfaxhd/

nasin Lasin

ilo nena li pana e sitelen "ASCII" e sitelen pona "UCSUR" ala.

ilo sona pi nasin ali li ken kepeken nasin ni.

nasin lupa

ilo nena li pana e sitelen pona kepeken nasin "R_ALT+U"

pi ilo sitelen "WinCompose". o kama jo e ona tan ma ni:

- https://github.com/ell1010/wincompose

nasin waso

ilo nena li pana e sitelen pona kepeken nasin "CTRL+SHIFT+U".

nasin kili

ilo nena li pana e sitelen pona kepeken nasin "Unicode Hex Input".

o kama jo e ona kepeken nasin ni:

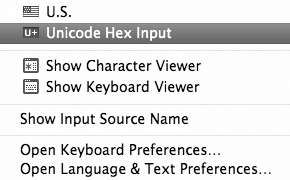
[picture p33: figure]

sina ken pana e sona sin tawa ilo nena!

tenpo ali la nasin sitelen Wakalito li kama sin. nasin sitelen Wakalito pi ilo nena kin li ken kama sin.

ilo nena li wawa ala la sina o pilin awen e nena o pana e wawa. ni la ma sitelen pi ilo nena li jo ala e sitelen. sina ken pana e sona sin tawa ilo nena kepeken ilo pi pana sona "minichlink" kepeken linja "USB".

sina ken kama jo e sona sin tan ma ni:

- https://ilonena.sadale.net/sona-sin

nimi ali pi nasin sitelen Wakalito

a A

akesi AKESI

ala ALA

alasa ALASA

ale ALE

anpa ANPA

ante ANTE

anu ANU

awen AWEN

e E

en EN

esun ESUN

ijo IJO

ike IKE

ilo ILO

insa INSA

jaki JAKI

jan JAN

jelo JELO

jo JO

kala KALA

kalama KALAMA

kama KAMA

kasi KASI

ken KEN

kepeken KEPEKEN

kili KILI

kin KIN

kiwen KIWEN

ko KO

kon KON

kule KULE

kulupu KULUPU

kute KUTE

la LA

lape LAPE

laso LASO

lawa LAWA

len LEN

lete LETE

li LI

lili LILI

linja LINJA

lipu LIPU

loje LOJE

lon LON

luka LUKA

lukin LUKIN

oko OKO

lupa LUPA

ma MA

mama MAMA

mani MANI

meli MELI

mi MI

mije MIJE

moku MOKU

moli MOLI

monsi MONSI

mu MU

mun MUN

musi MUSI

mute MUTE

namako NAMAKO

nanpa NANPA

nasa NASA

nasin NASIN

nena NENA

ni NI

nimi NIMI

noka NOKA

o O

olin OLIN

ona ONA

open OPEN

pakala PAKALA

pali PALI

palisa PALISA

pan PAN

pana PANA

pi PI

pilin PILIN

pimeja PIMEJA

pini PINI

pipi PIPI

poka POKA

poki POKI

pona PONA

pu PU

sama SAMA

seli SELI

selo SELO

seme SEME

sewi SEWI

sijelo SIJELO

sike SIKE

sin SIN

sina SINA

sinpin SINPIN

sitelen SITELEN

sona SONA

soweli SOWELI

suli SULI

suno SUNO

supa SUPA

suwi SUWI

tan TAN

taso TASO

tawa TAWA

telo TELO

tenpo TENPO

toki TOKI

tomo TOMO

tu TU

unpa UNPA

uta UTA

utala UTALA

walo WALO

wan WAN

waso WASO

wawa WAWA

weka WEKA

wile WILE

tonsi TONSI

monsuta MONSUTA

kijetesantakalu KIJETESANTAKALU

leko LEKO

kipisi KIPISI

apeja APEJA

jasima JASIMA

oke OKE

n N

soko SOKO

meso MESO

epiku EPIKU

kokosila KOKOSILA

lanpan LANPAN

misikeke MISIKEKE

ku KU

isipin ISIPIN

kapesi KAPESI

kiki KIKI

linluwi LINLUWI

mulapisu MULAPISU

pake PAKE

Pingo PINGO

powe POWE

unu UNU

wa WA

a a a

mi sona ala

,

:

↵

"

■

__

. . .

:>

:<

:|

:v

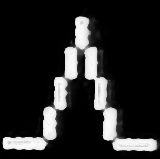
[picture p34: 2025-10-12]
user_manual/assets/awen.png

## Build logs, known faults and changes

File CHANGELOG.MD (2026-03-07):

2026-03-07 nanpa-ala:
* lipu kiwen sona "rev2": tenpo sama la jan li ken pilin e nena ali (NKRO); nasin USB la ilo awen 33R li kama lon
* poki: lupa li kama suli. ni la palisa li ken insa lupa ni lon tenpo ali
* pakala ni li kama weka: kepeken ilo "ibus" lon nasin waso "Linux" lon nasin sitelen "Czech" la ilo nena li ken ala pana e sitelen pona. nanpa pakala li #4
* tenpo ni la jan li pilin awen e nena "weka" la sitelen ali pi ilo nena li kama weka.
* ilo nena li pali tu: pali wan "tim2_task: tim2_task_pause()" en pali tu "rv003usb". tenpo pini la pali wan li pali la pali tu li wile awen. tenpo ni la pali wan li pali la pali tu li awen ala. ni la pali wan li kama awen.

2025-12-05 nanpa-akesi:
* pakala ni li kama weka: kepeken ilo "ibus" lon nasin waso "Linux" la jan li pilin e nena "PANA" la nimi tu sama li ken kama lon. nanpa pakala li #1

2025-11-22 nanpa-a:
* tenpo nanpa wan la ilonena.bin li kama lon!

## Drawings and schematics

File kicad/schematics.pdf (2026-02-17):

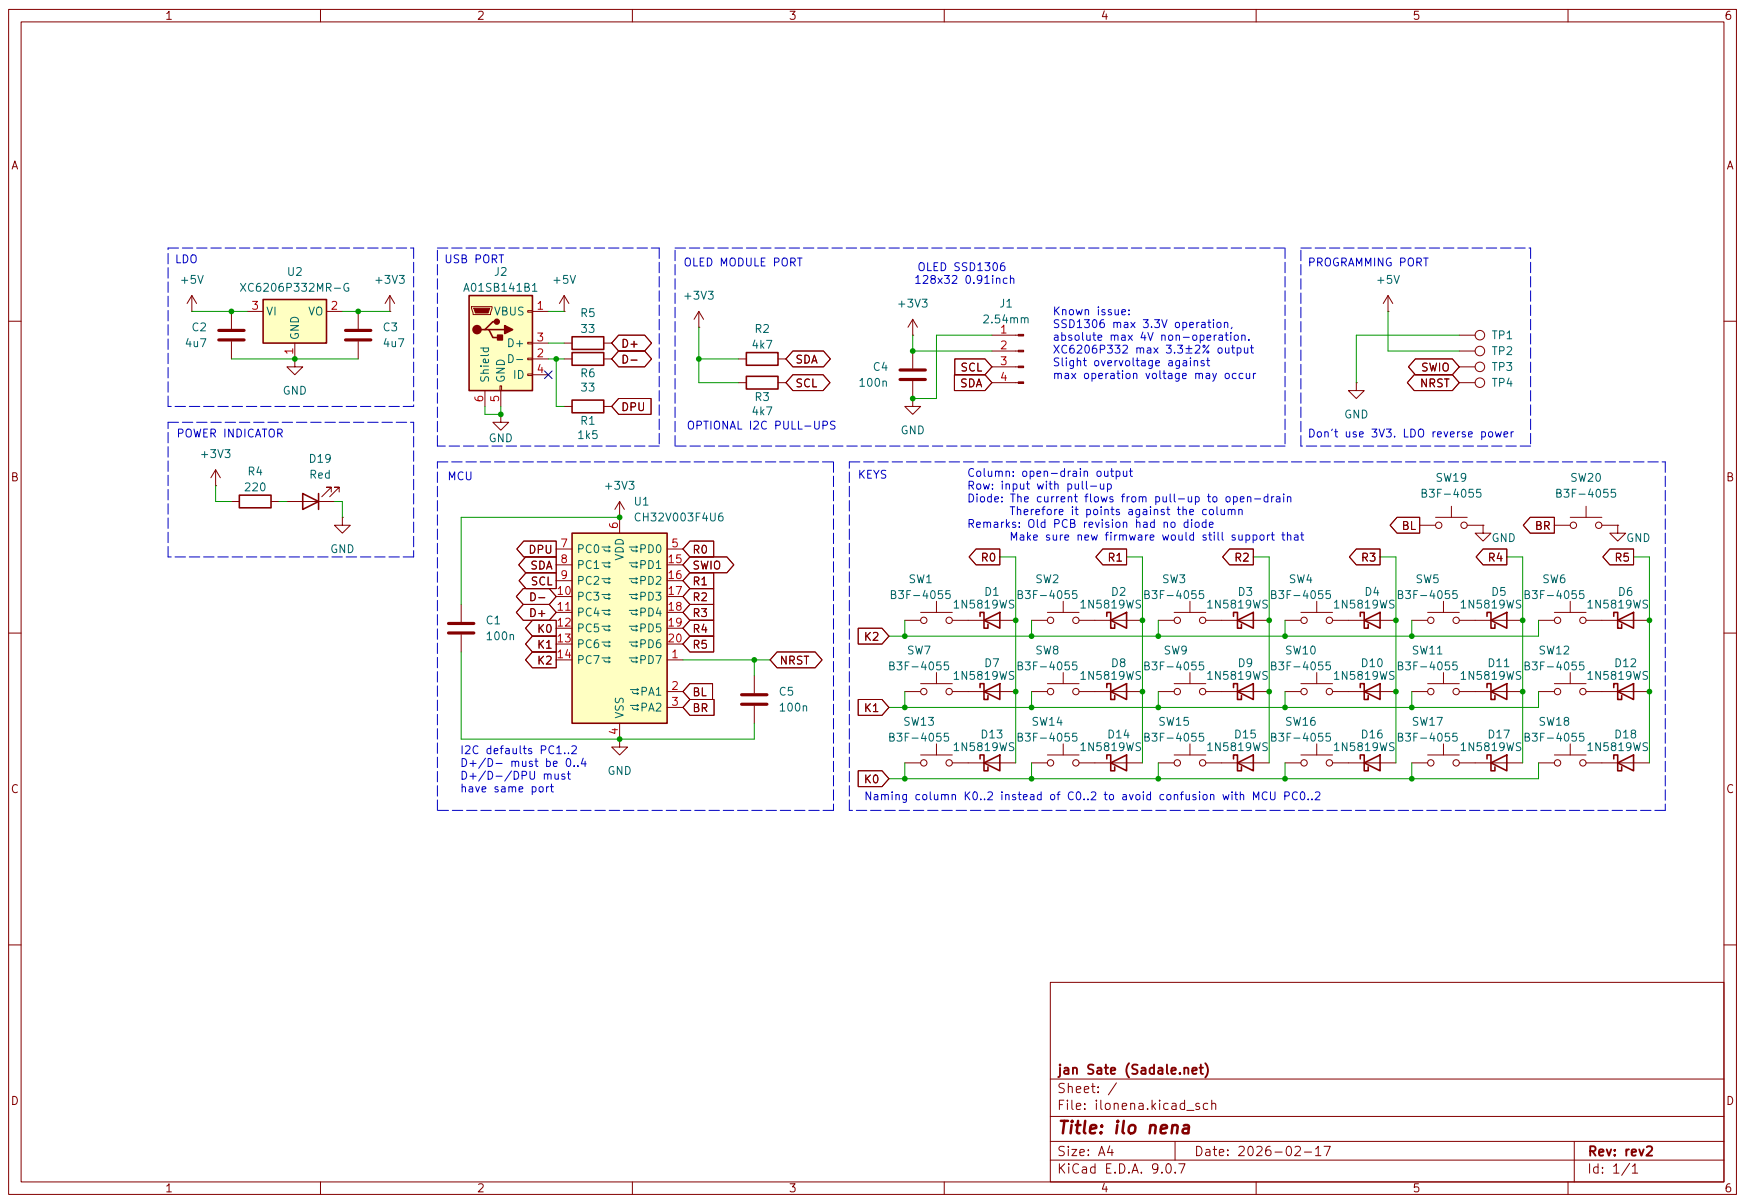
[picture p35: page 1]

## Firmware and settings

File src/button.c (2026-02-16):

// Copyright 2025 Wong Cho Ching <https://sadale.net>
//
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
// 1. Redistributions of source code must retain the above copyright
// notice, this list of conditions and the following disclaimer.
//
// 2. Redistributions in binary form must reproduce the above copyright
// notice, this list of conditions and the following disclaimer in the
// documentation and/or other materials provided with the distribution.
//
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
#include "tim2_task.h"
#include "ch32fun.h"

// Number of debounces required for the button state recorded as pressed/released
// The debounce state is initialized as zero, incremented if a press is detected, decremented else.
// The state is capped at [-BUTTON_DEBOUNCE_THRESHOLD, BUTTON_DEBOUNCE_THRESHOLD]
// Once it hits either BUTTON_DEBOUNCE_THRESHOLD or negative BUTTON_DEBOUNCE_THRESHOLD, it'd be recorded.
#define BUTTON_DEBOUNCE_THRESHOLD (4)

// Number of waiting required to register a button held event.
#define BUTTON_HELD_THRESHOLD (1000) // 1 second

// Column input config
#define BUTTON_COLUMN_GPIO_PORT (GPIOD)
// input, pull-up/pull-down mode
#define BUTTON_COLUMN_CFGLR_FLAG ((GPIO_CFGLR_CNF0_1|GPIO_CFGLR_CNF2_1|GPIO_CFGLR_CNF3_1|GPIO_CFGLR_CNF4_1|GPIO_CFGLR_CNF5_1|GPIO_CFGLR_CNF6_1))
#define BUTTON_COLUMN_CFGLR_MASK ((GPIO_CFGLR_MODE0|GPIO_CFGLR_MODE2|GPIO_CFGLR_MODE3|GPIO_CFGLR_MODE4|GPIO_CFGLR_MODE5|GPIO_CFGLR_MODE6) | (GPIO_CFGLR_CNF0|GPIO_CFGLR_CNF2|GPIO_CFGLR_CNF3|GPIO_CFGLR_CNF4|GPIO_CFGLR_CNF5|GPIO_CFGLR_CNF6))
// pull up
#define BUTTON_COLUMN_BSHR_FLAG (GPIO_BSHR_BS0|GPIO_BSHR_BS2|GPIO_BSHR_BS3|GPIO_BSHR_BS4|GPIO_BSHR_BS5|GPIO_BSHR_BS6)
// column mapping
const static uint32_t BUTTON_COLUMN_INDR_MASK_MAP[] = {GPIO_INDR_IDR0, GPIO_INDR_IDR2, GPIO_INDR_IDR3, GPIO_INDR_IDR4, GPIO_INDR_IDR5, GPIO_INDR_IDR6};
#define BUTTON_COLUMN_COUNT (sizeof(BUTTON_COLUMN_INDR_MASK_MAP)/sizeof(*BUTTON_COLUMN_INDR_MASK_MAP))

// Row output config
#define BUTTON_ROW_GPIO_PORT (GPIOC)
// output, open-drain, 2Mhz
#define BUTTON_ROW_CFGLR_FLAG ((GPIO_CFGLR_MODE5_1|GPIO_CFGLR_MODE6_1|GPIO_CFGLR_MODE7_1) | (GPIO_CFGLR_CNF5_0|GPIO_CFGLR_CNF6_0|GPIO_CFGLR_CNF7_0))
#define BUTTON_ROW_CFGLR_MASK ((GPIO_CFGLR_MODE5|GPIO_CFGLR_MODE6|GPIO_CFGLR_MODE7) | (GPIO_CFGLR_CNF5|GPIO_CFGLR_CNF6|GPIO_CFGLR_CNF7))
// row mapping: output LOW to the selected row and HIGH for other rows
#define BUTTON_ROW_BSHR_BS (GPIO_BSHR_BS5|GPIO_BSHR_BS6|GPIO_BSHR_BS7)
const static uint32_t BUTTON_ROW_BSHR_MASK_MAP[] = {
	(BUTTON_ROW_BSHR_BS&~GPIO_BSHR_BS7)|GPIO_BSHR_BR7,
	(BUTTON_ROW_BSHR_BS&~GPIO_BSHR_BS6)|GPIO_BSHR_BR6,
	(BUTTON_ROW_BSHR_BS&~GPIO_BSHR_BS5)|GPIO_BSHR_BR5,
};
#define BUTTON_ROW_COUNT (sizeof(BUTTON_ROW_BSHR_MASK_MAP)/sizeof(*BUTTON_ROW_BSHR_MASK_MAP))

// Dedicated button config (the buttons that's dedicated GPIO pin)
#define BUTTON_DEDICATED_GPIO_PORT (GPIOA)
// input, pull-up/pull-down mode
#define BUTTON_DEDICATED_CFGLR_FLAG (GPIO_CFGLR_CNF1_1|GPIO_CFGLR_CNF2_1)
#define BUTTON_DEDICATED_CFGLR_MASK ((GPIO_CFGLR_MODE1|GPIO_CFGLR_MODE2) | (GPIO_CFGLR_CNF1|GPIO_CFGLR_CNF2))
// pull up
#define BUTTON_DEDICATED_BSHR_FLAG (GPIO_BSHR_BS1|GPIO_BSHR_BS2)
const static uint32_t BUTTON_DEDICATED_INDR_MASK_MAP[] = {GPIO_INDR_IDR1, GPIO_INDR_IDR2};
#define BUTTON_DEDICATED_COUNT (sizeof(BUTTON_DEDICATED_INDR_MASK_MAP)/sizeof(*BUTTON_DEDICATED_INDR_MASK_MAP))
static size_t button_scan_row = 0;

uint32_t button_state = 0; // CONCURRENCY_VARIABLE: written/read by button_loop() via TIM2 ISR, read by button_get_state()
uint32_t button_press_event = 0; // CONCURRENCY_VARIABLE: written/read by button_loop() via TIM2 ISR, read by button_get_pressed_event()
uint32_t button_held_event = 0; // CONCURRENCY_VARIABLE: written/read by button_loop() via TIM2 ISR, read by button_get_held_event()

void button_init(void) {
	// Initialize the state variable(s)
	button_state = 0;
	button_press_event = 0;
	button_scan_row = 0;

	// Enable clock for GPIOA, GPIOC and GPIOD
	RCC->APB2PCENR |= (RCC_IOPAEN | RCC_IOPCEN | RCC_IOPDEN);

	// Configure row as output, open-drain, 2Mhz
	BUTTON_ROW_GPIO_PORT->CFGLR = (BUTTON_ROW_GPIO_PORT->CFGLR & ~BUTTON_ROW_CFGLR_MASK) | BUTTON_ROW_CFGLR_FLAG;
	// Write to the row for the first scan
	BUTTON_ROW_GPIO_PORT->BSHR = BUTTON_ROW_BSHR_MASK_MAP[button_scan_row];

	// Configure column as input, pull-up
	BUTTON_COLUMN_GPIO_PORT->CFGLR = (BUTTON_COLUMN_GPIO_PORT->CFGLR & ~BUTTON_COLUMN_CFGLR_MASK) | BUTTON_COLUMN_CFGLR_FLAG;
	BUTTON_COLUMN_GPIO_PORT->BSHR = BUTTON_COLUMN_BSHR_FLAG;

	// Configure dedicated button as input, pull-up
	BUTTON_DEDICATED_GPIO_PORT->CFGLR = (BUTTON_DEDICATED_GPIO_PORT->CFGLR & ~BUTTON_DEDICATED_CFGLR_MASK) | BUTTON_DEDICATED_CFGLR_FLAG;
	BUTTON_DEDICATED_GPIO_PORT->BSHR = BUTTON_DEDICATED_BSHR_FLAG;
}

static uint32_t button_handle_debounce(uint8_t reading, uint32_t state, int8_t debounce[], size_t index) {
	// Increases debounce count if button is pressed, decrease else
	// The button press/release is only recorded if a threshold is reached
	if(reading) {
		if(++debounce[index] >= BUTTON_DEBOUNCE_THRESHOLD) {
			debounce[index] = BUTTON_DEBOUNCE_THRESHOLD;
			state = (state & ~(1U << index)) | (1 << index);
		}
	} else {
		if(--debounce[index] <= -BUTTON_DEBOUNCE_THRESHOLD) {
			debounce[index] = -BUTTON_DEBOUNCE_THRESHOLD;
			state = (state & ~(1U << index));
		}
	}
	return state;
}
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

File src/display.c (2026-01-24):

// Copyright 2025 Wong Cho Ching <https://sadale.net>
//
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
// 1. Redistributions of source code must retain the above copyright
// notice, this list of conditions and the following disclaimer.
//
// 2. Redistributions in binary form must reproduce the above copyright
// notice, this list of conditions and the following disclaimer in the
// documentation and/or other materials provided with the distribution.
//
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
#include "display.h"
#include "tim2_task.h"
#include "ch32fun.h"
#include <stdlib.h>

#define DISPLAY_I2C_ADDR (0x3C)
#define DISPLAY_I2C_CLOCKRATE (100000) // SSD1306 supports up to 400kHz
#define DISPLAY_I2C_ERROR_FLAGS (I2C_STAR1_PECERR|I2C_STAR1_OVR|I2C_STAR1_AF|I2C_STAR1_ARLO|I2C_STAR1_BERR)

// Adapted from the sequence in the appendix of the SSD1306 specs
const static uint8_t display_init_array[] =
{
	0x00, // Control byte: the following bytes are to be treated as commands
	0xA8, 0x3F, // Set MUX ratio to 64MUX (0b111111)
	0xD3, 0x00, // Set display offset to 0
	0x40, // Set display start line to 0
	0xA1, // Set segment remap (column address 127 is mapped to SEG0)
	0xC8, // Set COM output scan direction to reverse (remapped mode. Scan from COM[N-1] to COM0)
	0xDA, 0x22, // Set COM pins hardware configuration (Sequential COM pin, Enable COM Left/Right remap)
	0x81, 0x7F, // Set Contrast Control (127)
	0xA4, // Entire Display on (0xA4 is display on, 0xA5 is display off)
	0xA6, // Non-inverted display (0xA7 is inverted display)
	0xD5, 0x80, // Set oscillator frequency (Fosc=1000b, Fdiv=0000b)
	0x8D, 0x14, // Enable charge pump regulator
	0xAF, // Display ON
};


#define DISPLAY_DATA_COMMAND_SIZE (20)
#define DISPLAY_DATA_SIZE (DISPLAY_WIDTH*4)

// CONCURRENCY_VARIABLE: read by display_loop() via TIM2 ISR, written by display_clear() / display_draw_*()
static uint8_t display_data_array[DISPLAY_DATA_COMMAND_SIZE+DISPLAY_DATA_SIZE] = {
	0x00, 0x00, 0x00, // Padding to make the graphc RAM area align with uint32_t
	0x80, 0x20, 0x80, 0x21, // Set memory addressing mode (Vertical addressing mode)
	0x80, 0x21, 0x80, 0x00, 0x80, 0x7F, // Setup column start and end address (0..127)
	0x80, 0x22, 0x80, 0x00, 0x80, 0x03, // Setup page start and end address (0..3)
	0x40, // all of the subsequent bytes are for OLED graphic RAM data.
	// 512 bytes of zeros (generated with Python `print((('0x00, '*16)[:-1] + '\n') * 32)`)
	0x00, 0x00, 0x00, 0x00, 0x00, 0x00, 0x00, 0x00, 0x00, 0x00, 0x00, 0x00, 0x00, 0x00, 0x00, 0x00,
	0x00, 0x00, 0x00, 0x00, 0x00, 0x00, 0x00, 0x00, 0x00, 0x00, 0x00, 0x00, 0x00, 0x00, 0x00, 0x00,
	0x00, 0x00, 0x00, 0x00, 0x00, 0x00, 0x00, 0x00, 0x00, 0x00, 0x00, 0x00, 0x00, 0x00, 0x00, 0x00,
	0x00, 0x00, 0x00, 0x00, 0x00, 0x00, 0x00, 0x00, 0x00, 0x00, 0x00, 0x00, 0x00, 0x00, 0x00, 0x00,
	0x00, 0x00, 0x00, 0x00, 0x00, 0x00, 0x00, 0x00, 0x00, 0x00, 0x00, 0x00, 0x00, 0x00, 0x00, 0x00,
	0x00, 0x00, 0x00, 0x00, 0x00, 0x00, 0x00, 0x00, 0x00, 0x00, 0x00, 0x00, 0x00, 0x00, 0x00, 0x00,
	0x00, 0x00, 0x00, 0x00, 0x00, 0x00, 0x00, 0x00, 0x00, 0x00, 0x00, 0x00, 0x00, 0x00, 0x00, 0x00,
	0x00, 0x00, 0x00, 0x00, 0x00, 0x00, 0x00, 0x00, 0x00, 0x00, 0x00, 0x00, 0x00, 0x00, 0x00, 0x00,
	0x00, 0x00, 0x00, 0x00, 0x00, 0x00, 0x00, 0x00, 0x00, 0x00, 0x00, 0x00, 0x00, 0x00, 0x00, 0x00,
	0x00, 0x00, 0x00, 0x00, 0x00, 0x00, 0x00, 0x00, 0x00, 0x00, 0x00, 0x00, 0x00, 0x00, 0x00, 0x00,
	0x00, 0x00, 0x00, 0x00, 0x00, 0x00, 0x00, 0x00, 0x00, 0x00, 0x00, 0x00, 0x00, 0x00, 0x00, 0x00,
	0x00, 0x00, 0x00, 0x00, 0x00, 0x00, 0x00, 0x00, 0x00, 0x00, 0x00, 0x00, 0x00, 0x00, 0x00, 0x00,
	0x00, 0x00, 0x00, 0x00, 0x00, 0x00, 0x00, 0x00, 0x00, 0x00, 0x00, 0x00, 0x00, 0x00, 0x00, 0x00,
	0x00, 0x00, 0x00, 0x00, 0x00, 0x00, 0x00, 0x00, 0x00, 0x00, 0x00, 0x00, 0x00, 0x00, 0x00, 0x00,
	0x00, 0x00, 0x00, 0x00, 0x00, 0x00, 0x00, 0x00, 0x00, 0x00, 0x00, 0x00, 0x00, 0x00, 0x00, 0x00,
	0x00, 0x00, 0x00, 0x00, 0x00, 0x00, 0x00, 0x00, 0x00, 0x00, 0x00, 0x00, 0x00, 0x00, 0x00, 0x00,
	0x00, 0x00, 0x00, 0x00, 0x00, 0x00, 0x00, 0x00, 0x00, 0x00, 0x00, 0x00, 0x00, 0x00, 0x00, 0x00,
	0x00, 0x00, 0x00, 0x00, 0x00, 0x00, 0x00, 0x00, 0x00, 0x00, 0x00, 0x00, 0x00, 0x00, 0x00, 0x00,
	0x00, 0x00, 0x00, 0x00, 0x00, 0x00, 0x00, 0x00, 0x00, 0x00, 0x00, 0x00, 0x00, 0x00, 0x00, 0x00,
	0x00, 0x00, 0x00, 0x00, 0x00, 0x00, 0x00, 0x00, 0x00, 0x00, 0x00, 0x00, 0x00, 0x00, 0x00, 0x00,
	0x00, 0x00, 0x00, 0x00, 0x00, 0x00, 0x00, 0x00, 0x00, 0x00, 0x00, 0x00, 0x00, 0x00, 0x00, 0x00,
	0x00, 0x00, 0x00, 0x00, 0x00, 0x00, 0x00, 0x00, 0x00, 0x00, 0x00, 0x00, 0x00, 0x00, 0x00, 0x00,
	0x00, 0x00, 0x00, 0x00, 0x00, 0x00, 0x00, 0x00, 0x00, 0x00, 0x00, 0x00, 0x00, 0x00, 0x00, 0x00,
	0x00, 0x00, 0x00, 0x00, 0x00, 0x00, 0x00, 0x00, 0x00, 0x00, 0x00, 0x00, 0x00, 0x00, 0x00, 0x00,
	0x00, 0x00, 0x00, 0x00, 0x00, 0x00, 0x00, 0x00, 0x00, 0x00, 0x00, 0x00, 0x00, 0x00, 0x00, 0x00,
	0x00, 0x00, 0x00, 0x00, 0x00, 0x00, 0x00, 0x00, 0x00, 0x00, 0x00, 0x00, 0x00, 0x00, 0x00, 0x00,
	0x00, 0x00, 0x00, 0x00, 0x00, 0x00, 0x00, 0x00, 0x00, 0x00, 0x00, 0x00, 0x00, 0x00, 0x00, 0x00,
	0x00, 0x00, 0x00, 0x00, 0x00, 0x00, 0x00, 0x00, 0x00, 0x00, 0x00, 0x00, 0x00, 0x00, 0x00, 0x00,
	0x00, 0x00, 0x00, 0x00, 0x00, 0x00, 0x00, 0x00, 0x00, 0x00, 0x00, 0x00, 0x00, 0x00, 0x00, 0x00,
	0x00, 0x00, 0x00, 0x00, 0x00, 0x00, 0x00, 0x00, 0x00, 0x00, 0x00, 0x00, 0x00, 0x00, 0x00, 0x00,
	0x00, 0x00, 0x00, 0x00, 0x00, 0x00, 0x00, 0x00, 0x00, 0x00, 0x00, 0x00, 0x00, 0x00, 0x00, 0x00,
	0x00, 0x00, 0x00, 0x00, 0x00, 0x00, 0x00, 0x00, 0x00, 0x00, 0x00, 0x00, 0x00, 0x00, 0x00, 0x00,
};
static uint8_t *const display_data_dma_start_address = &display_data_array[3];
static uint32_t *const display_data_buffer = (uint32_t*)&display_data_array[DISPLAY_DATA_COMMAND_SIZE];

#define DISPLAY_REFRESH_FLAG_INIT (1U<<0)
#define DISPLAY_REFRESH_FLAG_GRAPHIC (1U<<1)
uint8_t display_refresh_flag = 0; // CONCURRENCY_VARIABLE: written/read by display_loop() via TIM2 ISR, written/read by display_set_refresh_flag() / display_is_idle()

enum display_loop_step {
	DISPLAY_LOOP_STEP_IDLE,
	DISPLAY_LOOP_STEP_WAIT_TRANSFER, // common wait state shared by many SEND_ states
	DISPLAY_LOOP_STEP_WAIT_BUS_IDLE,
	DISPLAY_LOOP_STEP_SEND_START_BIT,
	DISPLAY_LOOP_STEP_SEND_ADDRESS,
	DISPLAY_LOOP_STEP_SEND_DATA_DMA,
	DISPLAY_LOOP_STEP_WAIT_DMA,
	DISPLAY_LOOP_STEP_SEND_END_BIT,
	DISPLAY_LOOP_STEP_SUCCESS,
	DISPLAY_LOOP_STEP_RESET_I2C_SETUP,
	DISPLAY_LOOP_STEP_RESET_I2C_CHECK_ERROR,
	DISPLAY_LOOP_STEP_RESET_I2C_SCL_HIGH,
};

#define DISPLAY_WAIT_SCL_FOR_I2C_RESET (FUNCONF_SYSTEM_CORE_CLOCK/DISPLAY_I2C_CLOCKRATE)
#define DISPLAY_WAIT_BUS_IDLE_TIMEOUT (FUNCONF_SYSTEM_CORE_CLOCK/1000 *3) // 3ms
#define DISPLAY_TRANSFER_TIMEOUT (FUNCONF_SYSTEM_CORE_CLOCK/1000 *3) // 3ms. For start bit, address and stop bit.
#define DISPLAY_DMA_TIMEOUT (FUNCONF_SYSTEM_CORE_CLOCK/1000 * 100) // 100ms. It takes 48ms to transfer 530 bytes at 100kHz.
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

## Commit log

2025-08-23 First commit with PCB first draft
    [ilonena.kicad_pcb, ilonena.kicad_sch]
2025-08-28 PCB rev0 design sent to JLCPCB.
    Changes made:
    * Rotated the OLED screen by 180deg
    * Changed the silk mark of the three special keys (baskcapce, enter and space)
    [ilonena.kicad_pcb, ilonena.kicad_sch]
2025-09-05 button: using low level registers instead of higher level functions for optimization
2025-09-06 button: Added handling code for extra buttons outside of the key matrix
2025-09-06 button: Using TIM2 timer interrupt for more precise timing as I foresee that more low-priority code will be implemented in the main loop in the future
2025-09-07 button: Implemented debouncing mechanism for robust key detection
2025-09-07 button: bugfix: Using open-drain output instead of push-pull to avoid short-circuit
    [button.c]
2025-09-07 button: Remove unused include: stdlib.h
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2025-09-14 display: first commit with working non-blocking I2C transfer support and preliminary error recovery mechanism
    [display.c]
2025-09-14 display: Implemented robust I2C error recovery mechanism
    [display.c]
2025-09-15 button: Replaced volatile button_state with memory barrier for performance optimization
    [button.c]
2025-09-15 display: Removed redundant error flag clearing; Made a macro for all I2C error flags; Clarified comment
    [display.c]
2025-09-15 display: Bugfix: DMA wrong bytes count for OLED initialization sequence
    [display.c]
2025-09-16 tim2_task: Moved execution of button_loop() and display_loop() to tim2_task; Also moved a few global varibles on display.c into display_loop() as static local variables
2025-09-16 display: Fixed I2C bus reset implementation. Now that there's a wait for SCL toggling
    [display.c]
2025-09-16 display: corrected terminology. Instead of calling it start/stop frame, call it start/stop bit. Also fixed comment on rationale not to use interrupt
    [display.c]
2025-09-16 display: rearranged error handling so that error condition got considered before normal condition. Also made timeout more lenient because the task timer triggers every 1ms so our timeout must be long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
    [display.c]
2025-09-19 button/display: Documented _loop() function's concurrency handling - they're allowed to preempt other functions
2025-09-20 button: Implemented button_get_pressed_event(); Also reduced tim2's polling interval to 0.5ms to enable short presses getting detected
    [button.c, tim2_task.c]
2025-09-20 keyboard: Implemented automated de-/activation of Num Lock and Caps Lock for typing in unicode
2025-09-20 display: Bugfix: after completion of DMA transfer, need to wait for completion of I2C transfer before sending the I2C stop bit
    [display.c]
2025-09-27 lookup: Added support for typing symbols (brackets, colon and comma)
2025-09-27 lookup: Attempting to reduce code size by combining data strings into one. Managed to cut 968 bytes (10172B -> 9204B)
2025-10-03 ui: Implemented blinking in case an invalid input sequence is given. Also fixed a bug that the enter key wasn't working when the input sequence is empty
2025-10-04 ui: Implemented entering persistent config mode by holding WEKA button during title screen
2025-10-06 button: reduced hold threshold from 3s to 1s
2025-10-06 keyboard: Fixed an edge case: extra trailing space after newline. The force_trailing_space should not force adding the trailing space for newline nor whitespace.
2025-10-07 enclosure: completed first revision. to be tested
    [ilonena_enclosure-Bottom.stl, ilonena_enclosure-Top_Rotated.stl, ilonena_enclosure.FCStd]
2025-10-07 enclosure: bottom part: enlarged the screw clearnce hole from 2.3mm to 2.5mm
    [ilonena_enclosure-Bottom.stl, ilonena_enclosure.FCStd]
2025-10-08 enclosure: Bottom part: added chamfer on the outline
    [ilonena_enclosure-Bottom.stl, ilonena_enclosure.FCStd]
2025-10-08 enclosure: top part: Added ridge on the edge of the screen slot for hiding the 2.54mm pin header; Added chamfer to outline
    [ilonena_enclosure-Top_Rotated.stl, ilonena_enclosure.FCStd]
2025-10-08 PCB: Update footprints to the one of KiCad 9.0.5; Replaced the pin header of SSD1306 from the thin circular pin header to the more common square-pin one for better compatibility; Bumped version numbe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
    [ilonena.kicad_pcb, ilonena.kicad_sch]
2025-10-12 user-manual: Added all remaining pages, including title page, package content, description of how each button works, config mode, font required, software required and USB flashing mode
2025-10-18 keycap-label: Fixed keycap label rendering by removing the red button background
2025-10-18 pcb: Added LCSC component ID for the 4k7 I2C pullup resistors. Added dot on U1 for clarification of the MCU orientation. Added Fabrication-Toolkit config file for JLCPCB; Moved the production directo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
    [ilonena.kicad_pcb, ilonena.kicad_sch]
2025-10-19 readme: Updated title graphic with enclosure
2025-10-19 readme: Clarified on the manufacture method of the enclosure; formatting
2025-10-20 pcb: Updated schematics version number for documentation purpose; Added schematics in PDF format; Added pre-rendered production files
    [ilonena.kicad_sch]
2025-10-23 readme: Added readme for printing user manual
2025-10-23 readme: Added readme file for enclosure with assembly instruction
2025-10-23 readme: enclosure: Clarified that ilonena_enclosure.FCStd is the source file in English; Also clarified that it's selo instead of poki in toki pona; Also tell the user to lift the screen protection f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
2025-10-24 readme: Added readme for keycap label describing how to transfer symbols onto the buttons
2025-10-24 readme: Added readme for the PCB/PCBA with instruction on how to order PCBA and how to solder the OLED
2025-10-25 enclosure: Enlarged the clearance hole from 2.5mm to 2.9mm to account for the shrinkage introduced by 3D printing process
    [ilonena_enclosure-Bottom.stl, ilonena_enclosure-Top_Rotated.stl, ilonena_enclosure.FCStd]
2025-10-26 readme: Added pic to bootloader flashing procedure, enclosure assembly and cardboard graphic printing. Also added requirement of option byte programming for bootloader flashing
2025-10-29 readme: Added pic for OLED assembly, keycap symbol stickers and user manual printing; Adjusted formatting
2025-10-30 Added full BOM with URL
    [full_bom.csv]
2025-10-30 readme: Added link to the official website; Added full assembly sequence; Corrected a BOM link; Added ilonena.bin in the license info
    [full_bom_batch_5.csv]
2025-11-16 readme: Changed title graphic to animated demo of the device
2025-11-20 BOM: Corrected cost of the OLED module
    [full_bom_batch_5.csv]
2026-01-09 enclosure: Added extra slack for OLED pin header. I found minor clashing between the pinheader and the enclosure with a few of the units
    [ilonena_enclosure-Top_Rotated.stl, ilonena_enclosure.FCStd]
2026-01-24 tim2_task: For race condition mitigation, instead of disabling global interrupts, now that I only disable the tim2's interrupt. It has a performance cost but that'd allow the USB interrupt to be trig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
2026-02-07 button: Changed key matrix I/O direction for reducing poll frequency. It helps with signal integrity
    [ilonena.kicad_sch]
2026-02-16 button: Fixed BUTTON_ROW_GPIO_PORT->BSHR initialization condition
    [button.c]
2026-02-17 PCB: rev2: added USB serial resistors, implemented NKRO support
    [ilonena.kicad_pcb, ilonena.kicad_sch]
2026-02-18 PCB: rev2: Modified diode footprint for ease of soldering; Moved the board's origin to a more reasonable plce
    [ilonena.kicad_pcb, ilonena.kicad_sch]
2026-02-23 electronics: PCB rev2: Added annotation for USB position adjustment for JLCPCB
    [ilonena.kicad_pcb, ilonena.kicad_sch]
2026-03-11 Clarification on use case of PCB rev2 in README
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
